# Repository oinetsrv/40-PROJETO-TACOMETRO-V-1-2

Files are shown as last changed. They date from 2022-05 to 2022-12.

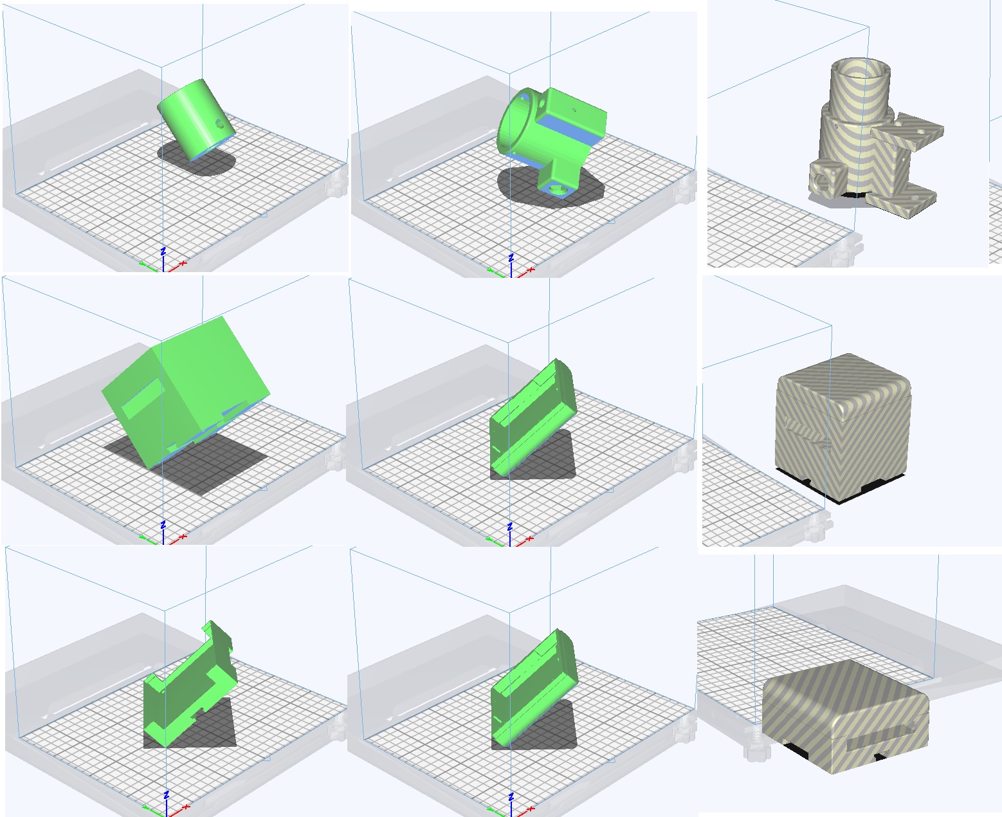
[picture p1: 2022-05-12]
DIAGRAMAS E IMAGENS/CASE-SENSOR.jpg

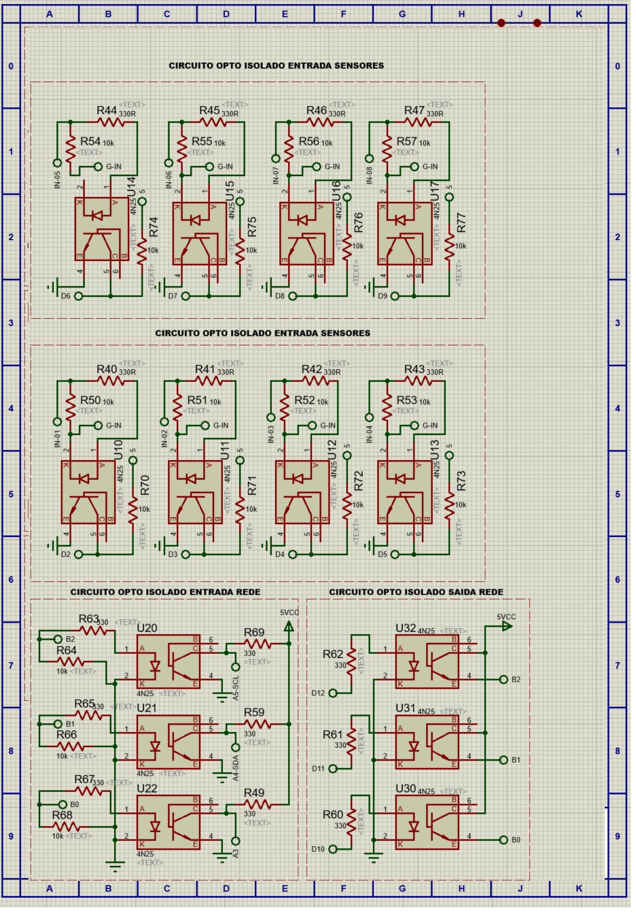
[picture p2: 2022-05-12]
DIAGRAMAS E IMAGENS/DIAGRAMA-PCB-I-O-P2.jpg

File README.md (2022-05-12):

# 40-PROJETO-TACOMETRO-V-1-2.
## MEDIDOR DE VELOCIDADE DE ROTAÇÃO USANDO MÉTODO DE INTERRUPÇÃO.
## COMUNICAÇÃO COM PROTOCOLO RS485.
## CAPACIDADE DE EXPANSÃO DAS ENTRADAS DIGITAIS EM MODULOS DE 8 ENTRADAS.
## REDE DE COMUNICAÇÃO MÁXIMA DE 4 MÓDULOS COM 8 ENTRADAS TOTAL DE SENSORES NA REDE DE 32 SENSORES.
## MODELAGEM 3D DAS CASES ADAPTADAS AO PADRÃO TRILHO DIN
## MODELAGEM 3D DA CASE DO SENSOR DE ROTAÇÃO ADAPTADA PARA FIXAÇÃO ROBUSTA NO CAMPO.
## MODELAGEM DAS PCBS DE I/O E REDE COM DIAGRAMA ELÉTRICO DETALHADO.

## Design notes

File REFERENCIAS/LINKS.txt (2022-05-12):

https://www.arduino.cc/reference/pt/language/functions/external-interrupts/attachinterrupt/

http://gammon.com.au/interrupts

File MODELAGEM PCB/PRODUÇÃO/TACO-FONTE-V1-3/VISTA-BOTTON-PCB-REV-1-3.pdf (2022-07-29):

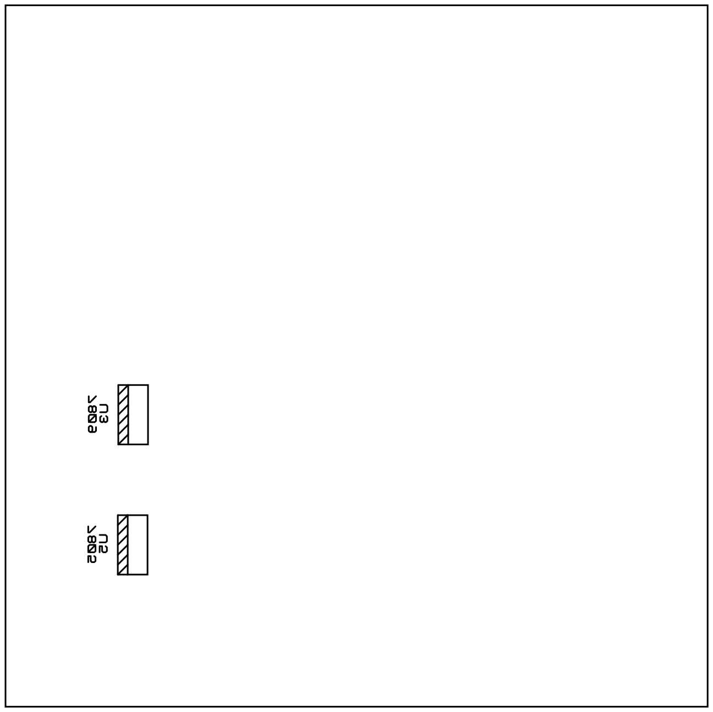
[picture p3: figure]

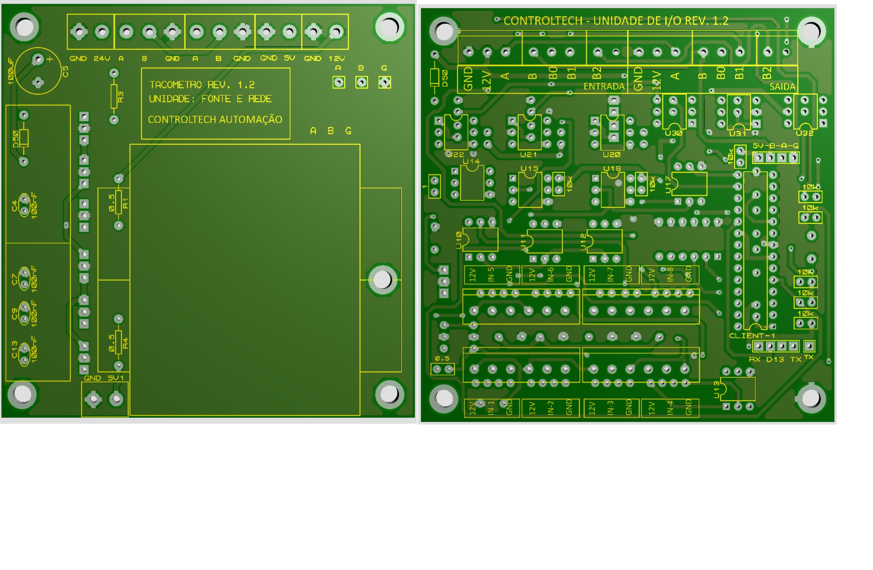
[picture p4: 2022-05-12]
DIAGRAMAS E IMAGENS/DIAGRAMA-PCB-I-O.jpg

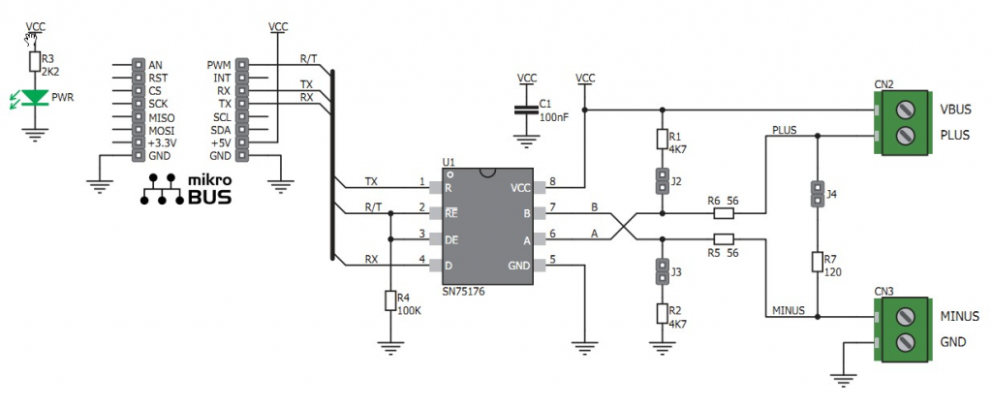
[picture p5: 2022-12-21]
REFERENCIAS/rede 485.png

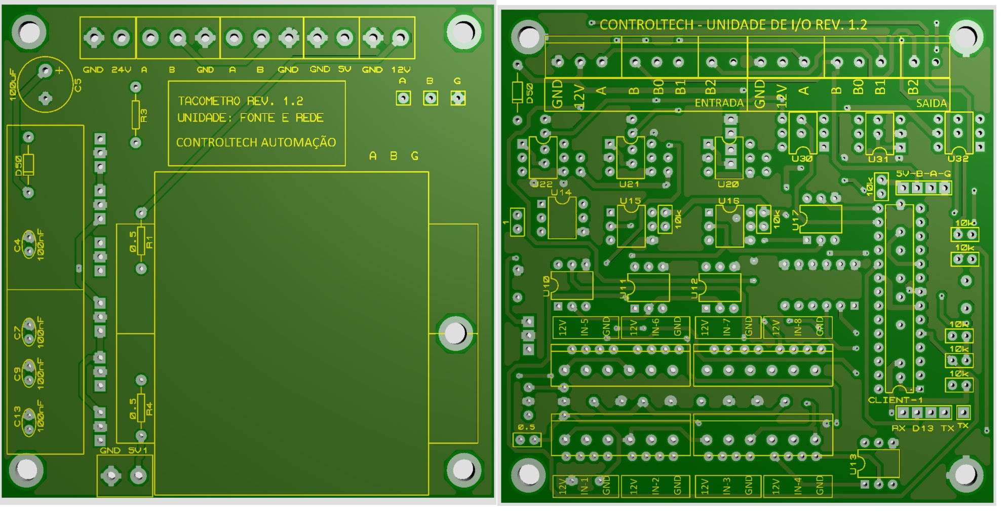
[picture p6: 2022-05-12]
DIAGRAMAS E IMAGENS/LAYOUT_PCBS.jpg

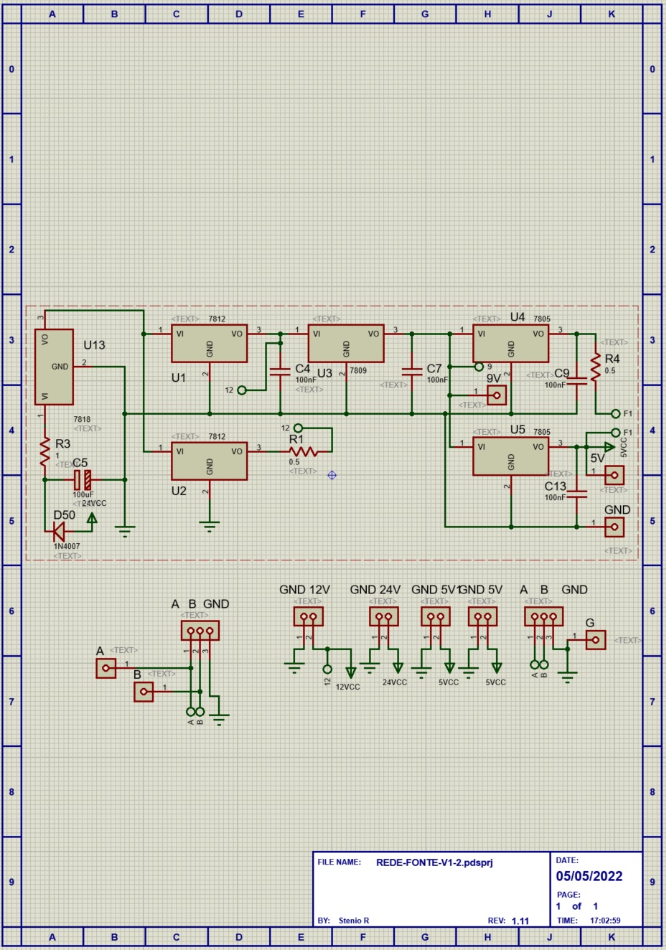
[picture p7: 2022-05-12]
DIAGRAMAS E IMAGENS/DIAGRAMA-PCB-FONTE-REDE.jpg

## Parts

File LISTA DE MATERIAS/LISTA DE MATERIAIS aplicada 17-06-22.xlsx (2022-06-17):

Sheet: MATERIAIS
 |  | FORNECIMENTO DE TACOMETRO ARMAZÉM DE GRÃOS |  |  |  |  |  | CLIENTE: TACOMETRO | PROPOSTA: 20221001 | REVISÃO: 01 | DATA DA PROPOSTA: 14/03/2022 | SOLICITANTE: HUGO
 |  |  |  |  |  |  |  |  |  |  |  |  |  | 50%
 | EQUIPAMENTOS
ITEM | DESCRIÇÃO | LOCAL | APLICAÇÃO | COD | UNID. | QUANT. | IPI | R$ Unit. S/ IPI | R$ Unit. C/ IPI | R$ Total Compra | MARG. % | R$ Unit. | R$ Total
1 | 08 SENSORES DE ROTAÇÃO
2 | EIXO PERFURADO TORNO |  | SENSOR |  | PÇ | 13 | 15% | R$82.00 | R$94.30 | R$1225.90 | 50% | R$141.45 | R$1838.85
3 | Fixador Magnético 36mm Furo Escareado |  | SENSOR |  | PÇ | 13 | 15% | R$92.50 | R$106.38 | R$1382.88 | 50% | R$159.56 | R$2074.31
1 | Fixador Magnético 20 Mm |  | SENSOR |  | PÇ | 13 | 15% | R$42.50 | R$48.88 | R$635.38 | 50% | R$73.31 | R$953.06
2 | SENSOR 100RPM-PNP |  | SENSOR |  | PÇ | 13 | 15% | R$112.00 | R$128.80 | R$1674.40 | 50% | R$193.20 | R$2511.60
4 | PRENSA CABO 1/8 |  | SENSOR |  | PÇ | 13 | 15% | R$3.50 | R$4.03 | R$52.33 | 50% | R$6.04 | R$78.49
6 | CASE IMPRESSÃO 3D MATERIAL COPO, BASE ROLAMENTO E PINO GUIA |  | SENSOR |  | PÇ | 13 | 15% | R$90.00 | R$103.50 | R$1345.50 | 50% | R$155.25 | R$2018.25
7 | IMPOSTO CASE 3D COPO, BASE ROLAMENTO E PINO GUIA |  | SENSOR |  | PÇ | 13 | 15% | R$60.00 | R$69.00 | R$897.00 | 50% | R$103.50 | R$1345.50
8 | PARAFUSO M4 IMA |  | SENSOR |  | PÇ | 13 | 15% | R$1.00 | R$1.15 | R$14.95 | 50% | R$1.73 | R$22.43
8 | PARAFUSO M8 BASE |  | SENSOR |  | PÇ | 26 | 15% | R$1.00 | R$1.15 | R$29.90 | 50% | R$1.73 | R$44.85
19 |  |  |  |  |  |  | 15% |  | R$0.00 | R$0.00 | 50% | R$0.00 | R$0.00
 | TOTAL MATERIAIS |  |  |  |  |  |  | R$483.50 |  | R$7258.23 |  |  | R$10887.34
 | PCB I/O
20 | CRISTAL 16MHZ |  | PCB I/O |  | PÇ | 1 | 15% | R$1.50 | R$1.73 | R$1.73 | 50% | R$2.59 | R$2.59
21 | ATMEGA328P-PU |  | PCB I/O |  | PÇ | 1 | 15% | R$35.00 | R$40.25 | R$40.25 | 50% | R$60.38 | R$60.38
22 | SOQUETE ESTAMPADO 28 PINOS ESTREITO |  | PCB I/O |  | PÇ | 8 | 15% | R$1.00 | R$1.15 | R$9.20 | 50% | R$1.73 | R$13.80
23 | CAPACITOR CERÂMICO 22PF 50V |  | PCB I/O |  | PÇ | 2 | 15% | R$0.50 | R$0.57 | R$1.15 | 50% | R$0.86 | R$1.73
24 | CAPACITOR CERÂMICO 100NF 50V |  | PCB I/O |  | PÇ | 7 | 15% | R$0.50 | R$0.57 | R$4.03 | 50% | R$0.86 | R$6.04
25 | CAPACITOR ELETROTR 100UF 50V |  | PCB I/O |  | PÇ | 0 | 15% | R$2.00 | R$2.30 | R$0.00 | 50% | R$3.45 | R$0.00
28 | METALFILME 1/4W 1% - 1K |  | PCB I/O |  | PÇ | 1 | 15% | R$0.50 | R$0.57 | R$0.57 | 50% | R$0.86 | R$0.86
29 | METALFILME 1/4W 1% - 1OHM |  | PCB I/O |  | PÇ | 1 | 15% | R$0.50 | R$0.57 | R$0.57 | 50% | R$0.86 | R$0.86
30 | METALFILME 1/4W 1% - 0.5OHM |  | PCB I/O |  | PÇ | 1 | 15% | R$0.50 | R$0.57 | R$0.57 | 50% | R$0.86 | R$0.86
31 | METALFILME 1/4W 1% - 330OHM |  | PCB I/O |  | PÇ | 20 | 15% | R$0.50 | R$0.57 | R$11.50 | 50% | R$0.86 | R$17.25
 | METALFILME 1/4W 1% - 10K |  | PCB I/O |  | PÇ | 20 | 15% | R$0.50 | R$0.57 | R$11.50 | 50% | R$0.86 | R$17.25
32 | CI 4N25 |  | PCB I/O |  | PÇ | 14 | 15% | R$3.00 | R$3.45 | R$48.30 | 50% | R$5.17 | R$72.45
 | CI 7805 |  | PCB I/O |  | PÇ | 2 | 15% | R$5.50 | R$6.33 | R$12.65 | 50% | R$9.49 | R$18.98
37 | CI 7809 |  | PCB I/O |  | PÇ | 1 | 15% | R$3.50 | R$4.03 | R$4.03 | 50% | R$6.04 | R$6.04
34 | MÓDULO ADAPTADOR TTL/RS485 |  | PCB I/O |  | PÇ | 1 | 15% | R$13.00 | R$14.95 | R$14.95 | 50% | R$22.43 | R$22.43
39 | DIODO 1N4007 |  | PCB I/O |  | PÇ | 1 | 15% | R$1.50 | R$1.73 | R$1.73 | 50% | R$2.59 | R$2.59
35 | BARRA DE PINO 1X20 MCI FÊMEA |  | PCB I/O |  | PÇ | 1 | 15% | R$9.00 | R$10.35 | R$10.35 | 50% | R$15.53 | R$15.53
 | TERMINAL DUPLO 2X6 VIAS de 3.81mm |  | PCB I/O |  | PÇ | 2 | 15% | R$16.00 | R$18.40 | R$36.80 | 50% | R$27.60 | R$55.20
 | BORNE RECEPTOR
40 | BR7MN2 - BORNE RECEPTOR 90º PASSO 3,81MM METALTEX 3VIAS |  | PCB I/O |  | PÇ | 4 | 15% | R$4.00 | R$4.60 | R$18.40 | 50% | R$6.90 | R$27.60
41 | BORNE PLUG METALTEX BR7F2 PASSO 3,81 MM 3 VIAS |  | PCB I/O |  | PÇ | 4 | 15% | R$4.50 | R$5.17 | R$20.70 | 50% | R$7.76 | R$31.05
42 | BR7MN2 - BORNE RECEPTOR 90º PASSO 3,81MM METALTEX 2VIAS |  | PCB I/O |  | PÇ | 2 | 15% | R$4.00 | R$4.60 | R$9.20 | 50% | R$6.90 | R$13.80
43 | BORNE PLUG METALTEX BR7F2 PASSO 3,81 MM 2VIAS |  | PCB I/O |  | PÇ | 2 | 15% | R$4.50 | R$5.17 | R$10.35 | 50% | R$7.76 | R$15.53
44 | PCB I/0 IMPORTADA PRINCIPAL |  | PCB I/O |  | PÇ | 1 | 15% | R$39.00 | R$44.85 | R$44.85 | 50% | R$67.28 | R$67.28
7 | IMPOSTO PCB |  | PCB I/O |  | PÇ | 1 | 15% | R$20.00 | R$23.00 | R$23.00 | 50% | R$34.50 | R$34.50
47 | DIP SWITCH 6 VIAS 180º |  | PCB I/O |  | PÇ | 1 | 15% | R$12.00 | R$13.80 | R$13.80 | 50% | R$20.70 | R$20.70
 | PARAFUSO M8 50MM |  | PCB I/O |  | PÇ | 4 | 15% | R$1.00 | R$1.15 | R$4.60 | 50% | R$1.73 | R$6.90
 | PORCA M8 |  | PCB I/O |  | PÇ | 16 | 15% | R$1.00 | R$1.15 | R$18.40 | 50% | R$1.73 | R$27.60
49 | CASE IMPRESSÃO 3D MATERIAL CASE E TAMPA |  | PCB I/O |  | PÇ | 1 | 15% | R$65.00 | R$74.75 | R$74.75 | 50% | R$112.12 | R$112.12
7 | IMPOSTO IMPRESSÃO CASE E TAMPA |  | PCB I/O |  | PÇ | 13 | 15% | R$35.00 | R$40.25 | R$523.25 | 50% | R$60.38 | R$784.88
 | QUANTIDADE DE PLACAS PARA A QUANTIDADE DE SENSORES |  |  |  |  | 1 |  | R$963.00 | R$963.00 | R$963.00 | 50% | R$1444.50 | R$1444.50
59 |  |  |  |  |  |  | 15% |  | R$0.00 | R$0.00 | 50% | R$0.00 | R$0.00
 | TOTAL MATERIAIS |  |  |  |  |  |  |  |  | R$1934.17 |  |  | R$2901.26
 | PCB REDE
24 | CAPACITOR CERÂMICO 100NF 50V |  | PCB REDE |  | PÇ | 3 | 15% | R$0.50 | R$0.57 | R$1.73 | 50% | R$0.86 | R$2.59
25 | CAPACITOR ELETROTR 100UF 50V |  | PCB REDE |  | PÇ | 0 | 15% | R$2.00 | R$2.30 | R$0.00 | 50% | R$3.45 | R$0.00
29 | METALFILME 1/4W 1% - 1OHM |  | PCB REDE |  | PÇ | 1 | 15% | R$0.50 | R$0.57 | R$0.57 | 50% | R$0.86 | R$0.86
30 | METALFILME 1/4W 1% - 0.5OHM |  | PCB REDE |  | PÇ | 0 | 15% | R$0.50 | R$0.57 | R$0.00 | 50% | R$0.86 | R$0.00
 | CI 7805 |  | PCB REDE |  | PÇ | 1 | 15% | R$5.50 | R$6.33 | R$6.33 | 50% | R$9.49 | R$9.49
37 | CI 7809 |  | PCB REDE |  | PÇ | 1 | 15% | R$6.30 | R$7.25 | R$7.25 | 50% | R$10.87 | R$10.87
 | CI 7812 |  | PCB REDE |  | PÇ | 0 | 15% | R$6.50 | R$7.47 | R$0.00 | 50% | R$11.21 | R$0.00
37 | CI 7818 |  | PCB REDE |  | PÇ | 0 | 15% | R$11.00 | R$12.65 | R$0.00 | 50% | R$18.98 | R$0.00
39 | DIODO 1N4007 |  | PCB REDE |  | PÇ | 1 | 15% | R$1.50 | R$1.73 | R$1.73 | 50% | R$2.59 | R$2.59
40 | BR7MN2 - BORNE RECEPTOR 90º PASSO 3,81MM METALTEX 3VIAS |  | PCB REDE |  | PÇ | 2 | 15% | R$4.00 | R$4.60 | R$9.20 | 50% | R$6.90 | R$13.80
41 | BORNE PLUG METALTEX BR7F2 PASSO 3,81 MM 3 VIAS |  | PCB REDE |  | PÇ | 2 | 15% | R$4.50 | R$5.17 | R$10.35 | 50% | R$7.76 | R$15.53
42 | BR7MN2 - BORNE RECEPTOR 90º PASSO 3,81MM METALTEX 2VIAS |  | PCB REDE |  | PÇ | 3 | 15% | R$4.00 | R$4.60 | R$13.80 | 50% | R$6.90 | R$20.70
43 | BORNE PLUG METALTEX BR7F2 PASSO 3,81 MM 2VIAS |  | PCB REDE |  | PÇ | 3 | 15% | R$4.50 | R$5.17 | R$15.53 | 50% | R$7.76 | R$23.29
64 | PCB I/0 IMPORTADA PRINCIPAL |  | PCB REDE |  | PÇ | 1 | 15% | R$35.00 | R$40.25 | R$40.25 | 50% | R$60.38 | R$60.38
7 | IMPOSTO PCB |  | PCB REDE |  | PÇ | 1 | 15% | R$20.00 | R$23.00 | R$23.00 | 50% | R$34.50 | R$34.50
 | PARAFUSO M8 50MM |  | PCB REDE |  | PÇ | 4 | 15% | R$1.00 | R$1.15 | R$4.60 | 50% | R$1.73 | R$6.90
 | PORCA M8 |  | PCB REDE |  | PÇ | 16 | 15% | R$1.00 | R$1.15 | R$18.40 | 50% | R$1.73 | R$27.60
49 | CASE IMPRESSÃO 3D MATERIAL CASE E TAMPA |  | PCB REDE |  | PÇ | 1 | 15% | R$65.00 | R$74.75 | R$74.75 | 50% | R$112.12 | R$112.12
7 | IMPOSTO IMPRESSÃO CASE E TAMPA |  | PCB REDE |  | PÇ | 13 | 15% | R$35.00 | R$40.25 | R$523.25 | 50% | R$60.38 | R$784.88
69 | CONVERSOR USR-TCP232-410S SUPORT DNS DHCP RS232 RS485 SERIAL |  | PCB REDE |  | PÇ | 1 | 15% | R$425.00 | R$488.75 | R$488.75 | 50% | R$733.12 | R$733.12
 | QUANTIDADE DE PLACAS PARA A QUANTIDADE DE SENSORES |  |  |  |  | 1 |  | R$963.00 | R$963.00 | R$963.00 | 50% | R$1444.50 | R$1444.50
78 |  |  |  |  |  |  | 15% |  | R$0.00 | R$0.00 | 50% | R$0.00 | R$0.00
 | TOTAL MATERIAIS |  |  |  |  |  |  |  |  | R$2202.47 |  |  | R$3303.70
84
85
86
87
88
100
 | TOTAL MATERIAIS CONTEMPLA 12 SENSORES, 2 PLACA I/O E 1 PLACA DE REDE |  |  |  |  |  |  |  |  | R$0.00 |  |  | R$17092.31
49 | TOTAL MÃO DE OBRA |  |  |  |  |  |  |  |  |  |  |  | #NAME?
 | TOTAL PROPOSTA |  |  |  |  |  |  |  |  |  |  |  | #NAME?
 |  |  |  |  |  |  |  |  |  |  |  |  | R$5127.69
 |  |  |  |  |  |  |  |  |  |  |  |  | #NAME?

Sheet: MO
MÃO DE OBRA
ITEM | DESCRIÇÃO | DIAS | H. DIA | HORAS | OFICIAL | AJUD. | T. FUNC. | R$ OFICIAL | R$ AJUD. | R$ M-O | MAR. % | R$ M-O T. | HOSP. | T. HOSP | ALIM. | T. ALIM. | KM | KM TOTAL | R$ KM | R$ T. KM | ADICIONAL | TOTAL | TOTAL+ADIC.
1 | INFRAESTRUTURA, FIXAÇÃO DO PAINEL E PASSAGEM DE CABOS | 4 | 8 | 32 | 1 | 2 | 3 | R$65.00 | R$35.00 | R$4320.00 | 30% | R$5616.00 | R$75.00 | R$900.00 | R$25.00 | R$300.00 |  | 0 | R$1.44 | R$0.00 | R$2500.00 | R$6816.00 | R$9316.00
2 | PASSAGEM DE CABOS | 2 | 8 | 16 | 1 | 2 | 3 | R$65.00 | R$35.00 | R$2160.00 | 30% | R$2808.00 | R$75.00 | R$450.00 | R$25.00 | R$150.00 |  | 0 | R$1.44 | R$0.00 |  | R$3408.00 | R$3408.00
3 |  |  | 8 | 0 | 1 | 3 | 4 | R$65.00 | R$35.00 | R$0.00 | 30% | R$0.00 |  | R$0.00 | R$25.00 | R$0.00 |  | 0 | R$1.44 | R$0.00 |  | R$0.00 | R$0.00
4 |  |  | 8 | 0 | 1 | 3 | 4 | R$65.00 | R$35.00 | R$0.00 | 30% | R$0.00 |  | R$0.00 | R$25.00 | R$0.00 |  | 0 | R$1.44 | R$0.00 |  | R$0.00 | R$0.00
5 |  |  | 8 | 0 | 1 | 3 | 4 | R$65.00 | R$35.00 | R$0.00 | 30% | R$0.00 |  | R$0.00 | R$25.00 | R$0.00 |  | 0 | R$1.44 | R$0.00 |  | R$0.00 | R$0.00
6 |  |  | 8 | 0 | 1 | 2 | 3 | R$90.00 | R$45.00 | R$0.00 | 30% | R$0.00 |  | R$0.00 | R$25.00 | R$0.00 |  | 0 | R$1.44 | R$0.00 |  | R$0.00 | R$0.00
7 |  |  | 8 | 0 | 1 | 2 | 3 | R$90.00 | R$45.00 | R$0.00 | 30% | R$0.00 |  | R$0.00 | R$25.00 | R$0.00 |  | 0 | R$1.44 | R$0.00 |  | R$0.00 | R$0.00
 |  |  |  |  |  |  |  |  |  |  |  |  |  |  |  |  |  |  |  |  |  |  | R$1017.92
 |  |  |  |  |  |  |  |  |  |  |  |  |  |  |  |  |  |  |  |  | TOTAL ELETRICA |  | R$12724.00
 |  |  |  |  |  |  |  |  |  |  |  |  |  |  | FORNECIMENTO CONTROL TECH
 |  |  |  |  |  |  |  |  |  |  |  |  |  |  | ITEM | DESCRIÇÃO |  |  |  |  |  | DESC. | R$ VALOR
 |  |  |  |  |  |  |  |  |  |  |  |  |  |  | 1 | INFRAESTRUTURA, FIXAÇÃO DO PAINEL E PASSAGEM DE CABOS |  |  |  |  |  | SERVIÇO | R$13741.92
 |  |  |  |  |  |  | AUT | R$0.00 |  | 0.00% |  | R$0.00 |  |  | 2 | PASSAGEM DE CABOS |  |  |  |  |  | SERVIÇO
 |  |  |  |  |  |  | ELE | R$12724.00 |  | 100.00% |  | R$13741.92 |  |  | 3 |  |  |  |  |  |  | SERVIÇO
 |  |  |  |  |  |  |  |  |  |  |  |  |  |  | 4 |  |  |  |  |  |  | SERVIÇO
 |  |  |  |  |  |  |  |  |  |  |  |  |  |  | 5 |  |  |  |  |  |  | SERVIÇO
 |  |  |  |  |  |  |  |  |  |  |  |  |  |  | 6 |  |  |  |  |  |  | SERVIÇO
 |  |  |  |  |  |  |  |  |  |  |  |  |  |  | 7 |  |  |  |  |  |  | SERVIÇO
 |  |  |  |  |  |  |  |  |  |  |  |  |  |  | 8 |  |  |  |  |  |  | SERVIÇO
 |  |  |  |  |  |  |  |  |  |  |  |  |  |  | 9 |  |  |  |  |  |  | SERVIÇO
 |  |  |  |  |  |  |  |  |  |  |  |  |  |  | 10 |  |  |  |  |  |  | SERVIÇO
 |  |  |  |  |  |  |  |  |  |  |  |  |  |  |  | VALOR MÃO DE OBRA |  |  |  |  |  |  | R$13741.92

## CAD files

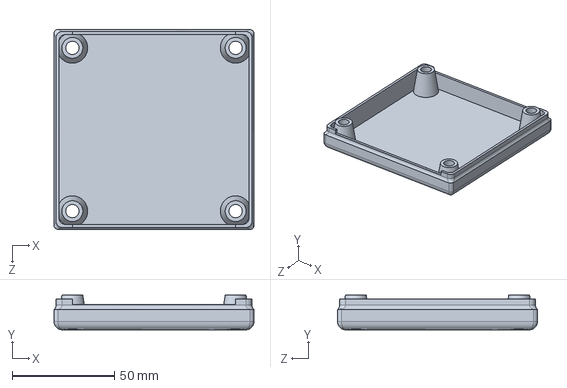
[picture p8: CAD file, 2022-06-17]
MODELAGEM 3D/PRODUÇÃO/CASE TAMPA V8.SLDPRT
98.0 x 17.0 x 98.0 mm

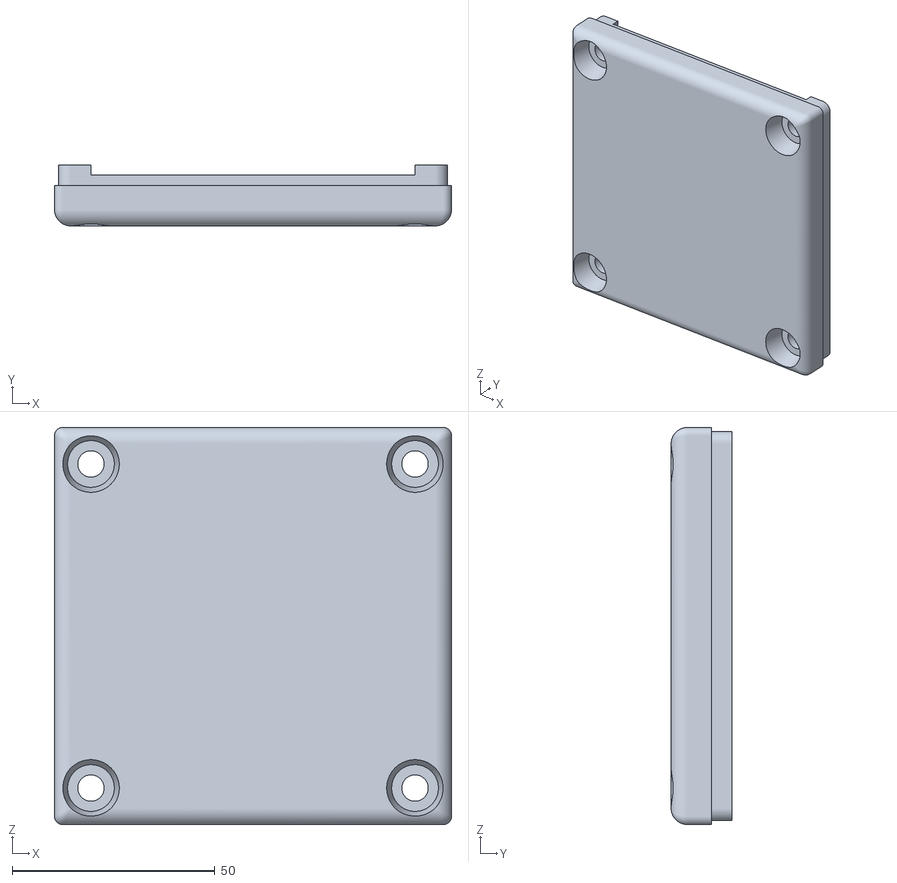
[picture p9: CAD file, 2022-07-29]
MODELAGEM 3D/PRODUÇÃO25-07/CASE IO TAMPA V9.STL
98.0 x 15.0 x 98.0

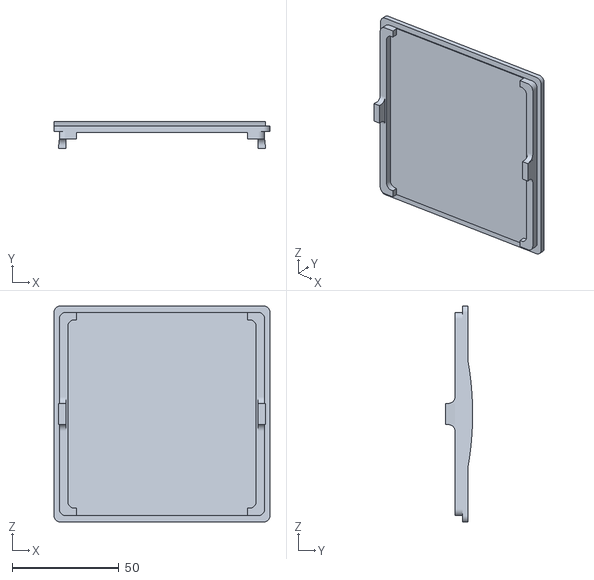
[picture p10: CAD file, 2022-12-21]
MODELAGEM 3D/CASE TAMPA V12.STL
101.0 x 12.7 x 101.0

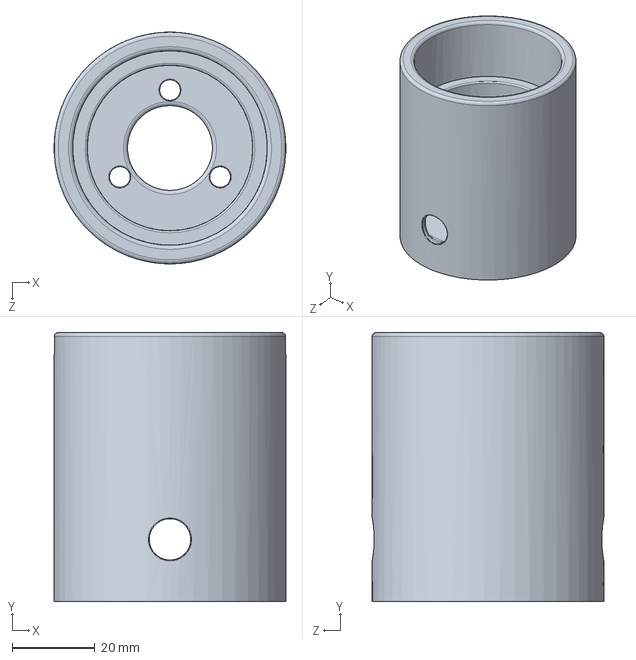
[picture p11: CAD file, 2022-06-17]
MODELAGEM 3D/PRODUÇÃO/BASE-ROLAMENTO-V2.SLDPRT
56.0 x 65.0 x 56.0 mm

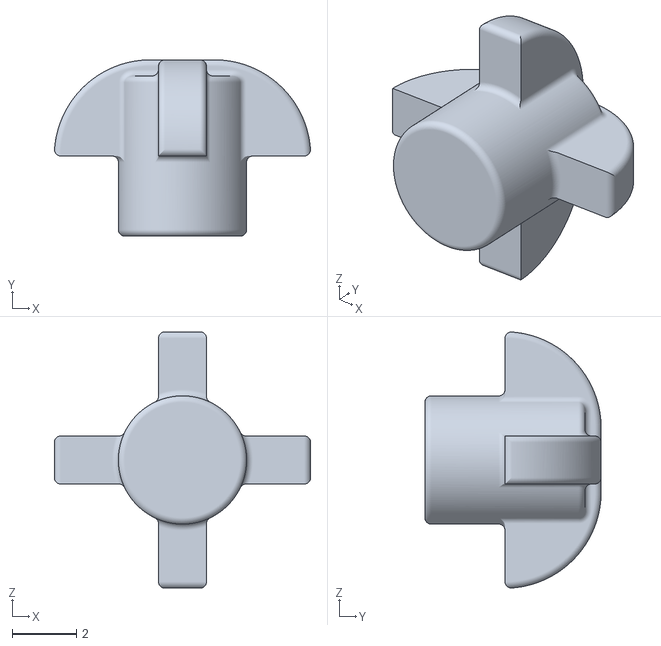
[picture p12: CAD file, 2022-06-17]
MODELAGEM 3D/PRODUÇÃO25-07/PINO-GUIA-V2.STL
7.99 x 5.50 x 7.99

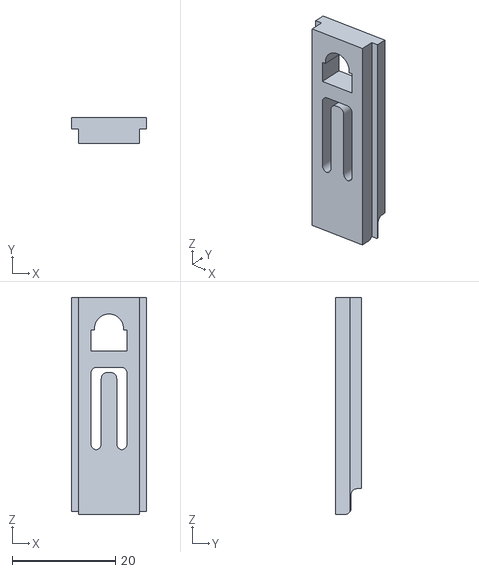
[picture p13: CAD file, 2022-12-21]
MODELAGEM 3D/PINO-TRAVA-DIN-V2.STL
14.5 x 5.00 x 42.0

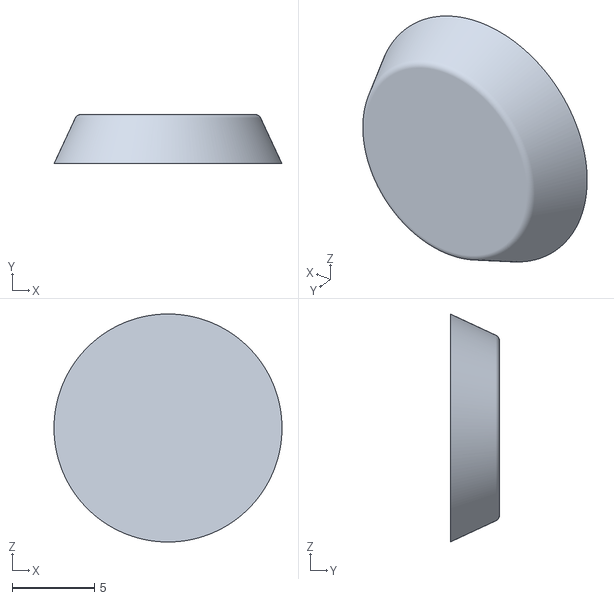
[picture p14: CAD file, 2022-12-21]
MODELAGEM 3D/CAIXA-TAMPA-PARAFUSO.STL
13.9 x 3.00 x 13.9

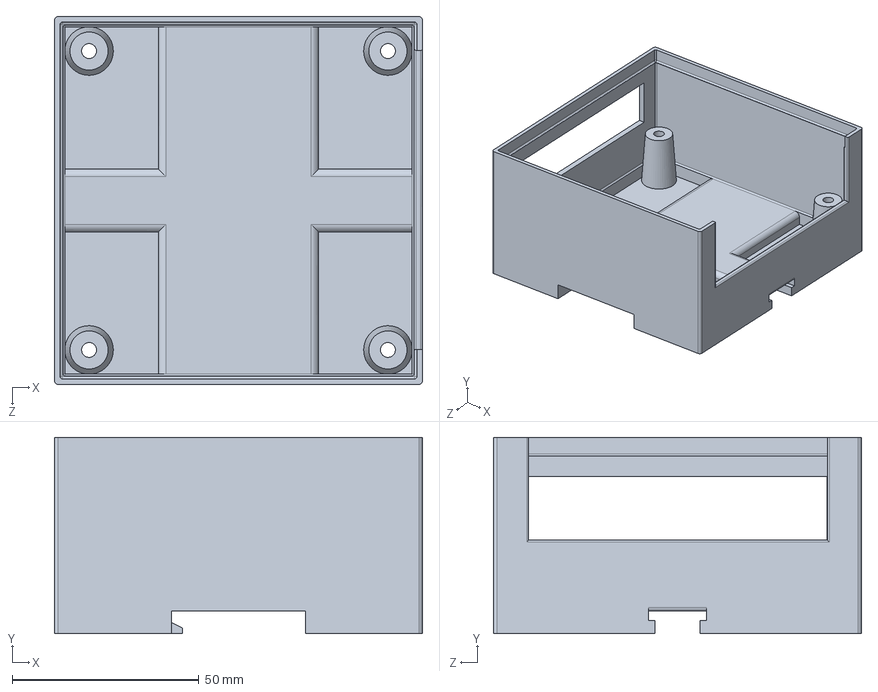
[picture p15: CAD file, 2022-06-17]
MODELAGEM 3D/PRODUÇÃO/CASE IO V7.SLDPRT
98.5 x 52.5 x 98.5 mm

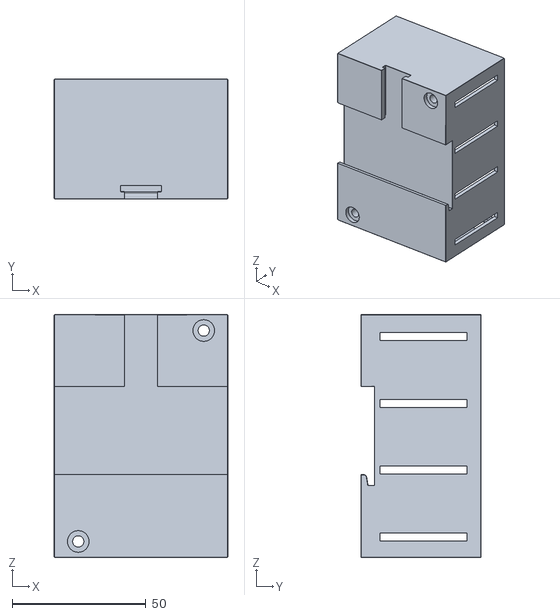
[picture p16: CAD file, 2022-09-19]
MODELAGEM 3D/CAIXA-DIN-REDE-V5.STL
65.0 x 45.0 x 91.0

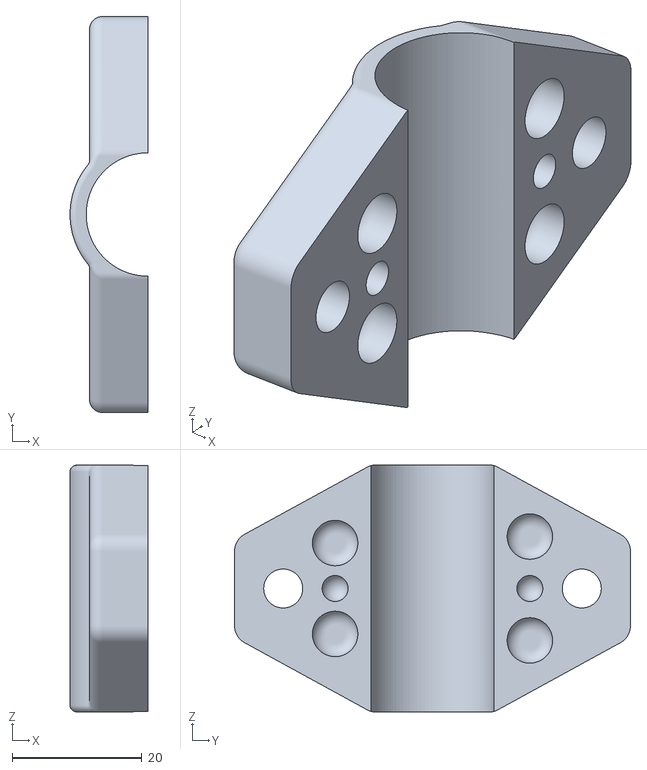
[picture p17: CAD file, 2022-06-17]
MODELAGEM 3D/PRODUÇÃO/COLAR-P1-V2.STL
12.0 x 61.0 x 38.0

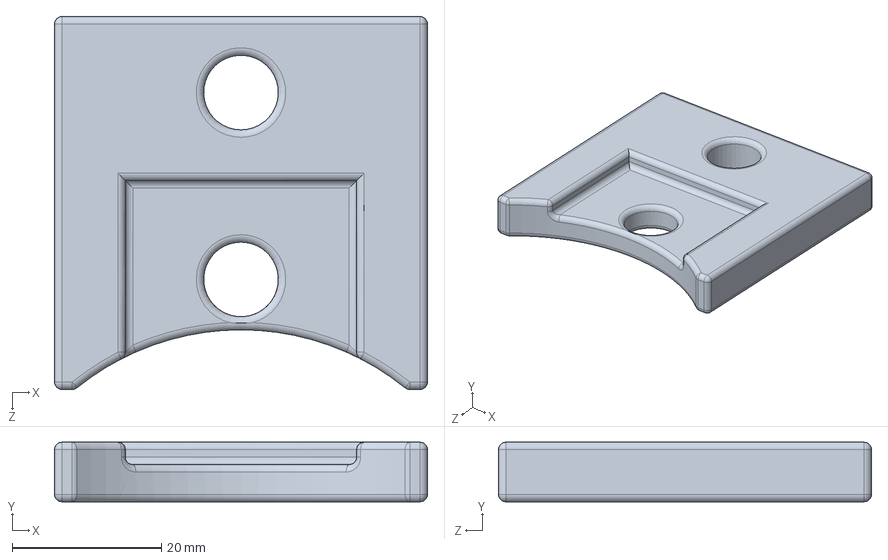
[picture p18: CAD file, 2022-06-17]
MODELAGEM 3D/PRODUÇÃO/SUPORTE-EXTENSOR-V3.SLDPRT
50.0 x 8.00 x 50.0 mm

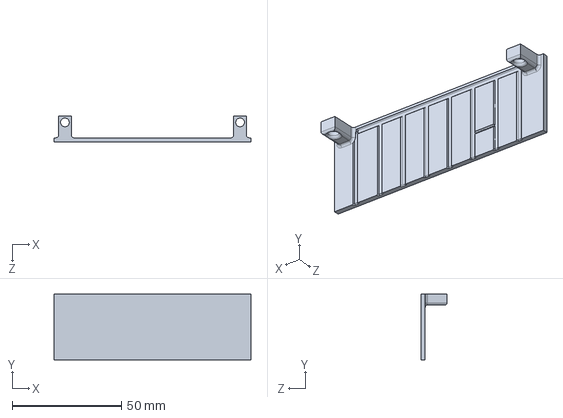
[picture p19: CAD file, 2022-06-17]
MODELAGEM 3D/CASE-ESPELHO-V1.SLDPRT
90.0 x 30.0 x 12.0 mm

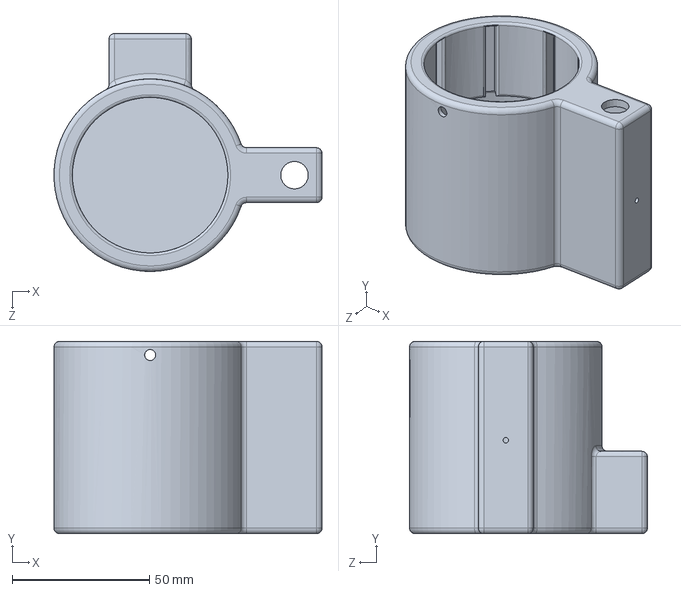
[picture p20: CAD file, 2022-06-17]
MODELAGEM 3D/PRODUÇÃO/COPO-ROLAMENTO-V10.SLDPRT
97.5 x 70.0 x 86.5 mm

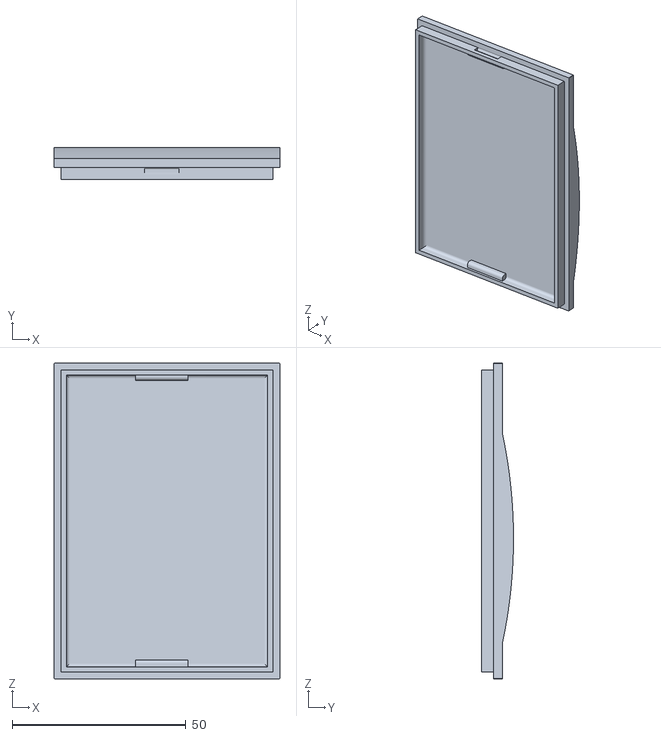
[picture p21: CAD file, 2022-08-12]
MODELAGEM 3D/versoes anteriores/CAIXA-DIN-TAMPA-REDE-V4.STL
65.0 x 9.22 x 91.0

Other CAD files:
MODELAGEM 3D/PRODUÇÃO/PINO-GUIA-V2.SLDPRT
MODELAGEM 3D/CAIXA-DIN-TAMPA-FONTE-V5.STL
MODELAGEM 3D/COLAR-P1-V2.SLDPRT
MODELAGEM 3D/CASE TAMPA V11.STL
MODELAGEM 3D/PRODUÇÃO/CASE IO V7.STL
MODELAGEM 3D/PRODUÇÃO/CASE TAMPA V8.STL
MODELAGEM 3D/PRODUÇÃO/SUPORTE-EXTENSOR-V3.STL
MODELAGEM 3D/versoes anteriores/CAIXA-DIN-FONTE-V1.STL
MODELAGEM 3D/versoes anteriores/CAIXA-DIN-FONTE-V3.STL
MODELAGEM 3D/versoes anteriores/CAIXA-DIN-FONTE-V4.STL
MODELAGEM 3D/versoes anteriores/CAIXA-DIN-REDE-V1.STL
MODELAGEM 3D/versoes anteriores/CAIXA-DIN-REDE-V3.STL
MODELAGEM 3D/versoes anteriores/CAIXA-DIN-REDE-V4.STL
MODELAGEM 3D/versoes anteriores/CAIXA-DIN-TAMPA-FONTE-V1.STL
MODELAGEM 3D/versoes anteriores/CAIXA-DIN-TAMPA-FONTE-V2.STL
MODELAGEM 3D/versoes anteriores/CAIXA-DIN-TAMPA-FONTE-V3.STL
MODELAGEM 3D/versoes anteriores/CASE-ESPELHO-V1.STL
MODELAGEM 3D/versoes anteriores/COLAR-P2-V2.SLDPRT
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

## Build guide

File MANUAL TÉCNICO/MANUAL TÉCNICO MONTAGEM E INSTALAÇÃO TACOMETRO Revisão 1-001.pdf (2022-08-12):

# MANUAL TÉCNICO

## MONTAGEM E INSTALAÇÃO

## MONITOR DE ROTAÇÃO – CTS100

# CONTROLTECH AUTOMAÇÃO INDUSTRIAL

Revisão 1.001

Rio Verde, Julho de 2022

## Sumário

## 1. Lista de figuras

## 2. Introdução

Este é um sistema composto por uma fonte de alimentação dedicada, placa conversora de

sinais mistos, placa de comunicação conversora de protocolos de comunicação e sensor de

rotação. Funciona monitorando a rotação de motores a fim de detectar rotações excessivas ou

baixas. Isso é feito por monitores de rotação no qual geram pulsos proporcionais ao giro do

motor.
Devido à sua construção mecânica, possui fácil acoplamento magnético ao eixo. É uma

solução prática para problemas com monitoramento de rotação em qualquer equipamento de

eixo rotativo. Aplicado em diversos lugares como por exemplo: transportadores de correia,

elevadores, roscas transportadoras e transportadores de arraste, entre outros...

### Características técnicas:

- Leituras velocidade de 0-100 rpm;
- Possui protocolo de comunicação aberto RS485 ou Ethernet TCP/IP;
- Grau de Proteção IP65 (a prova de poeira e protegido contra jatos de água);
- Fornece informações sobre a velocidade ou rotação do eixo;
- Principais aplicações: transportadores, elevadores, misturadores, ventiladores,

bombas, trituradores e outros;

## 3. Diagrama PCB I/O CTI008 Rer. 1.6

Diagrama de montagem dos componentes da PCB I/O revisão 1.6

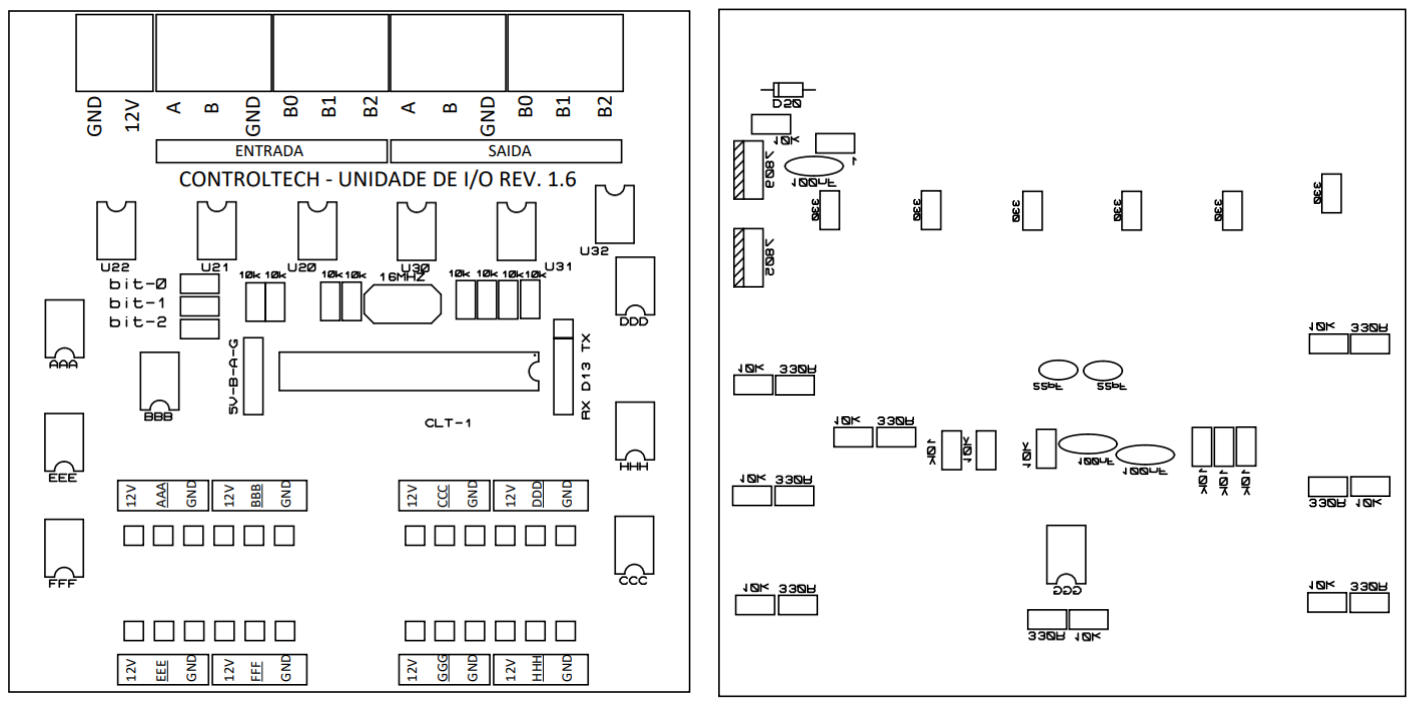
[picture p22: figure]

Figura 1: Vista superior e inferior PCB I/O Ver. 1.6

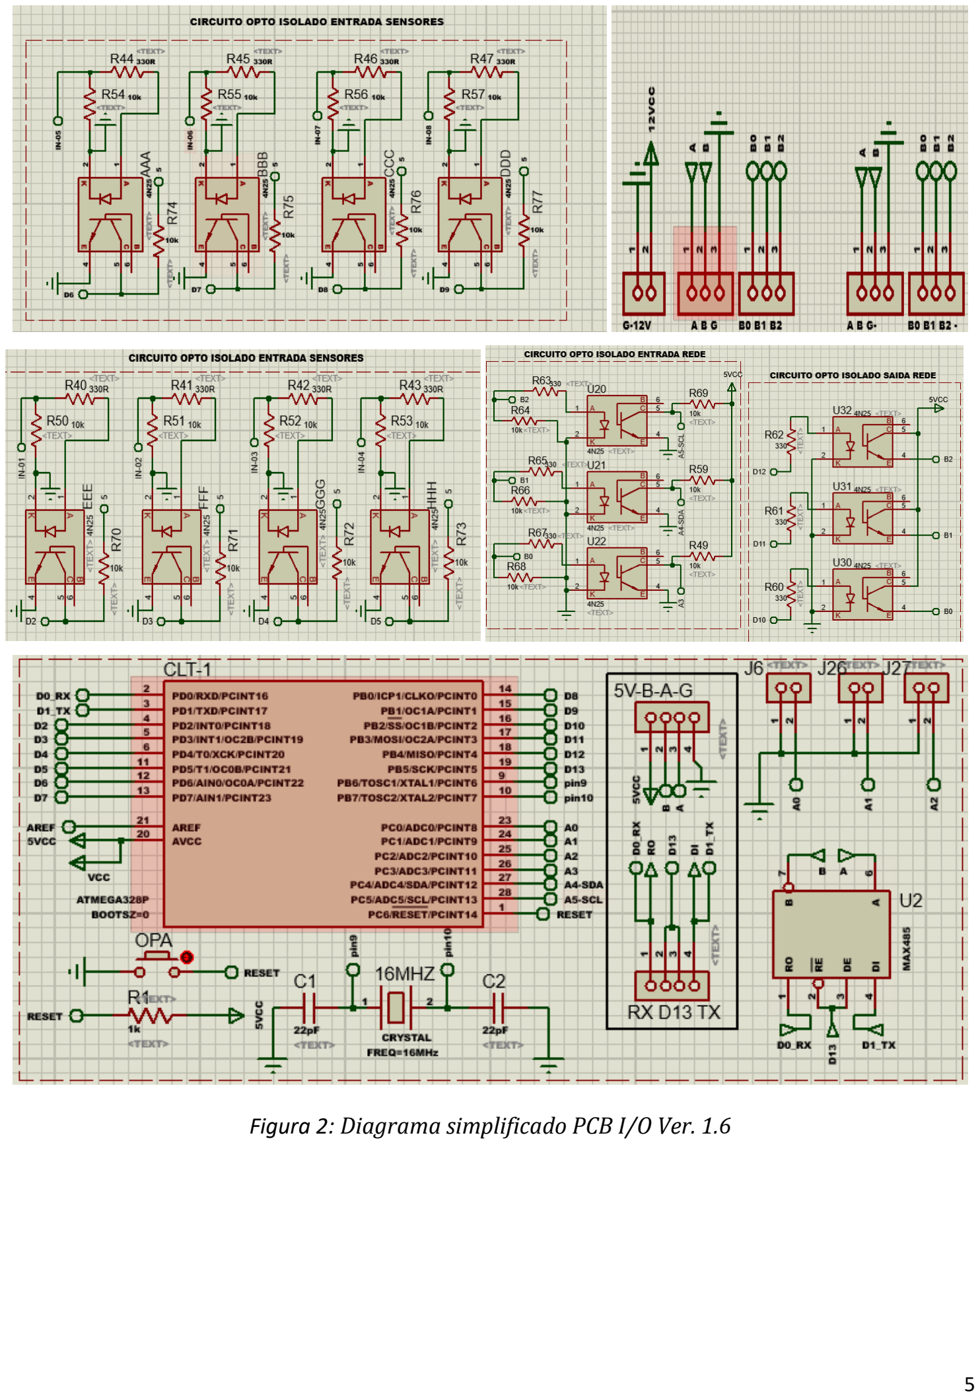
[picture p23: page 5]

Figura 2: Diagrama simplificado PCB I/O Ver. 1.6

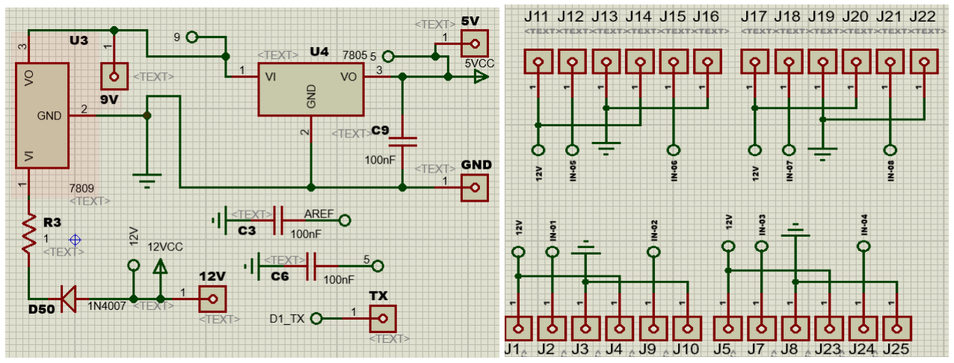
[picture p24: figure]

Figura 3: diagrama simplificado PCB I/O Ver. 1.6

### Principais componentes PCB I/O CTI008 Rer. 1.6

Os conectores identificados na PCB são os bornes modelo 2EDGVC e 2EDGVC com seus respectivos conectores.

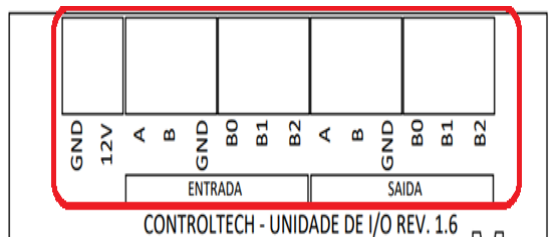
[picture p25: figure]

Figura 4: Detalhe conectores PCB I/O Ver. 1.6

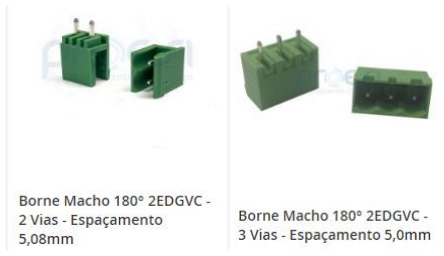
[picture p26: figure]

Figura 5: Conectores PCB

Os componentes identificados na PCB são os acopladores ópticos 4N25

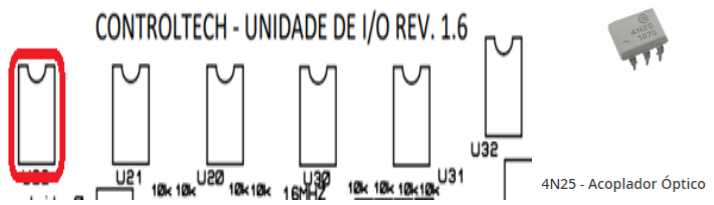
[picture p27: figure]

Figura 6: Detalhe componente 4N25 PCB I/O Ver. 1.6

Os componentes identificados na PCB com a seta verde são a matriz de jumpers, a seta azul é o cristal de 16 MHz, a seta vermelha são os resistores de 10k, a seta cinza são barras de Pinos Fêmea para conectar o modulo de comunicação RS485 e por fim a seta amarela representa o microcontrolador 328p.

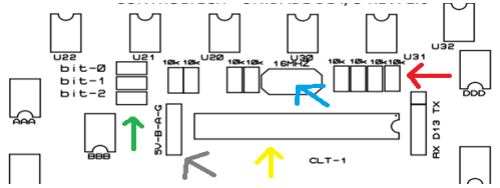
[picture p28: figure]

Figura 7: Detalhe PCB I/O Ver. 1.6

Os componentes identificados na PCB são os terminais de 3.81mm com camada dupla

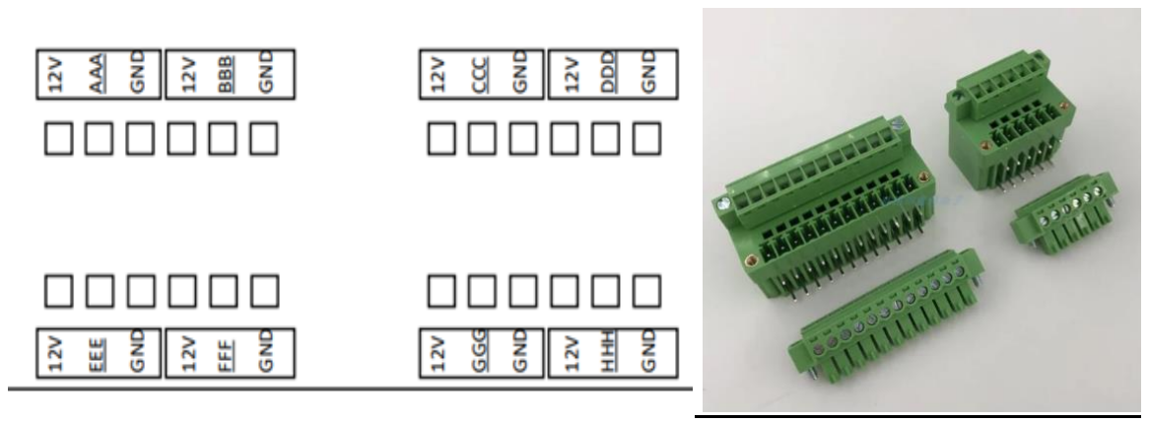
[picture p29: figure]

Figura 8: Detalhe PCB I/O Ver. 1.6 e detalhe conector entrada sensor

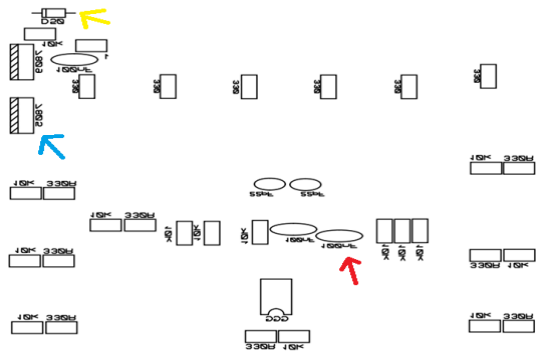
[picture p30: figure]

Figura 9: Detalhe PCB I/O Ver. 1.6

Os componentes identificados na PCB com a seta amarela é o diodo 1N4007 componente polarizado atenção ao montar. Componente identificado com a senta azul são os controladores de tensão. Componentes com a senta vermelha são capacitores.

## 4. Sensor de rotação CTS100 Rer. 1.0

Segue abaixo detalhes de montagem do sensor

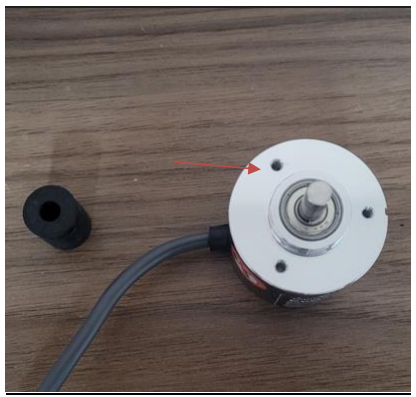
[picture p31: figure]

Figura 10: Sensor de rotação, pontos de fixação do sensor ao suporte

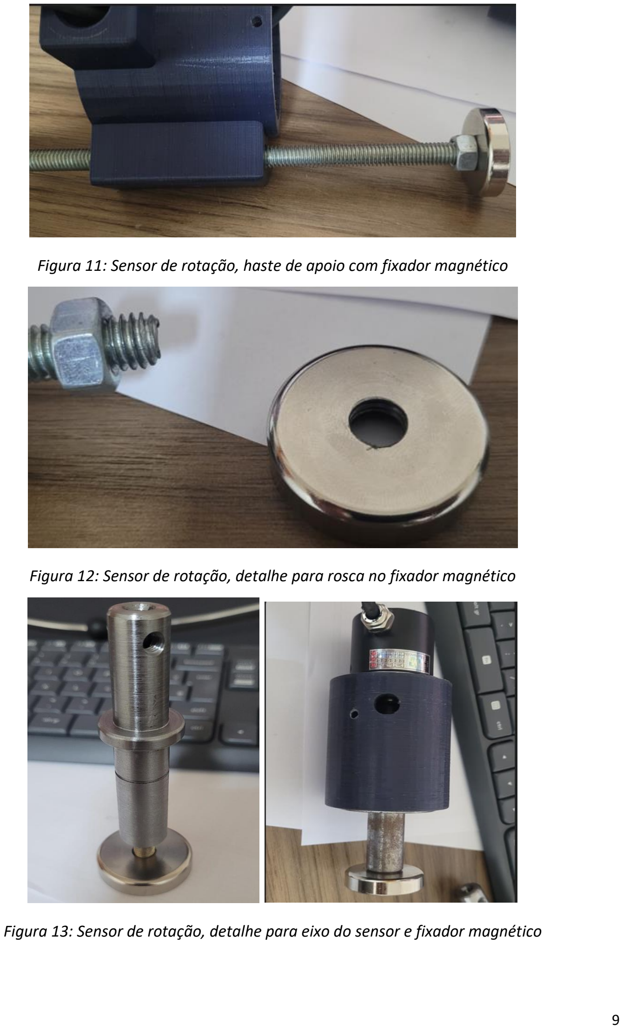
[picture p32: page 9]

Figura 11: Sensor de rotação, haste de apoio com fixador magnético

Figura 12: Sensor de rotação, detalhe para rosca no fixador magnético

Figura 13: Sensor de rotação, detalhe para eixo do sensor e fixador magnético

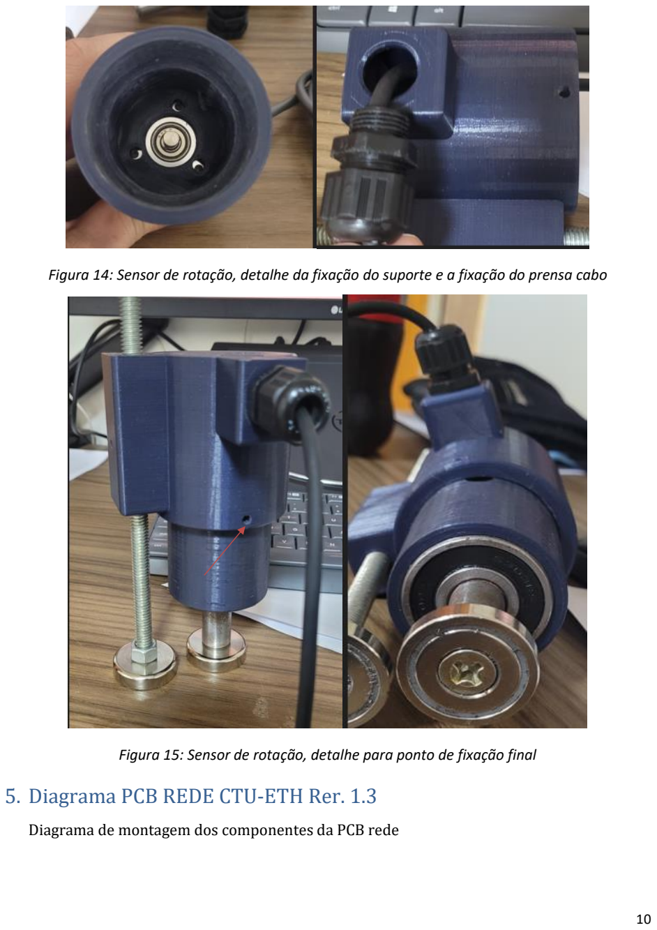
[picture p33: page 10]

Figura 14: Sensor de rotação, detalhe da fixação do suporte e a fixação do prensa cabo

Figura 15: Sensor de rotação, detalhe para ponto de fixação final

## 5. Diagrama PCB REDE CTU-ETH Rer. 1.3

Diagrama de montagem dos componentes da PCB rede

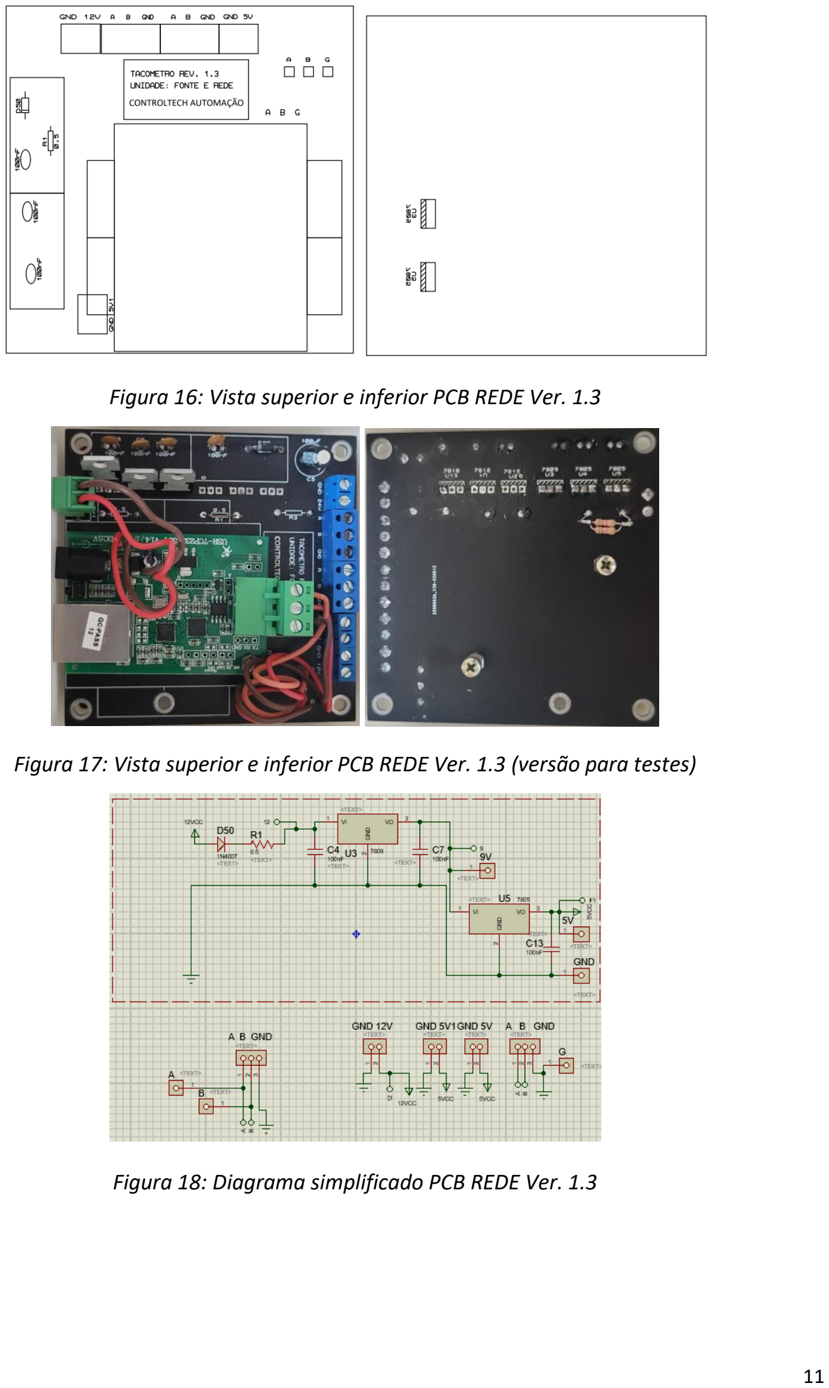
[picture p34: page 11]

Figura 16: Vista superior e inferior PCB REDE Ver. 1.3

Figura 17: Vista superior e inferior PCB REDE Ver. 1.3 (versão para testes)

Figura 18: Diagrama simplificado PCB REDE Ver. 1.3

## 6. Diagrama de instalação do conjunto placa I/O fonte de alimentação e

placa de rede.

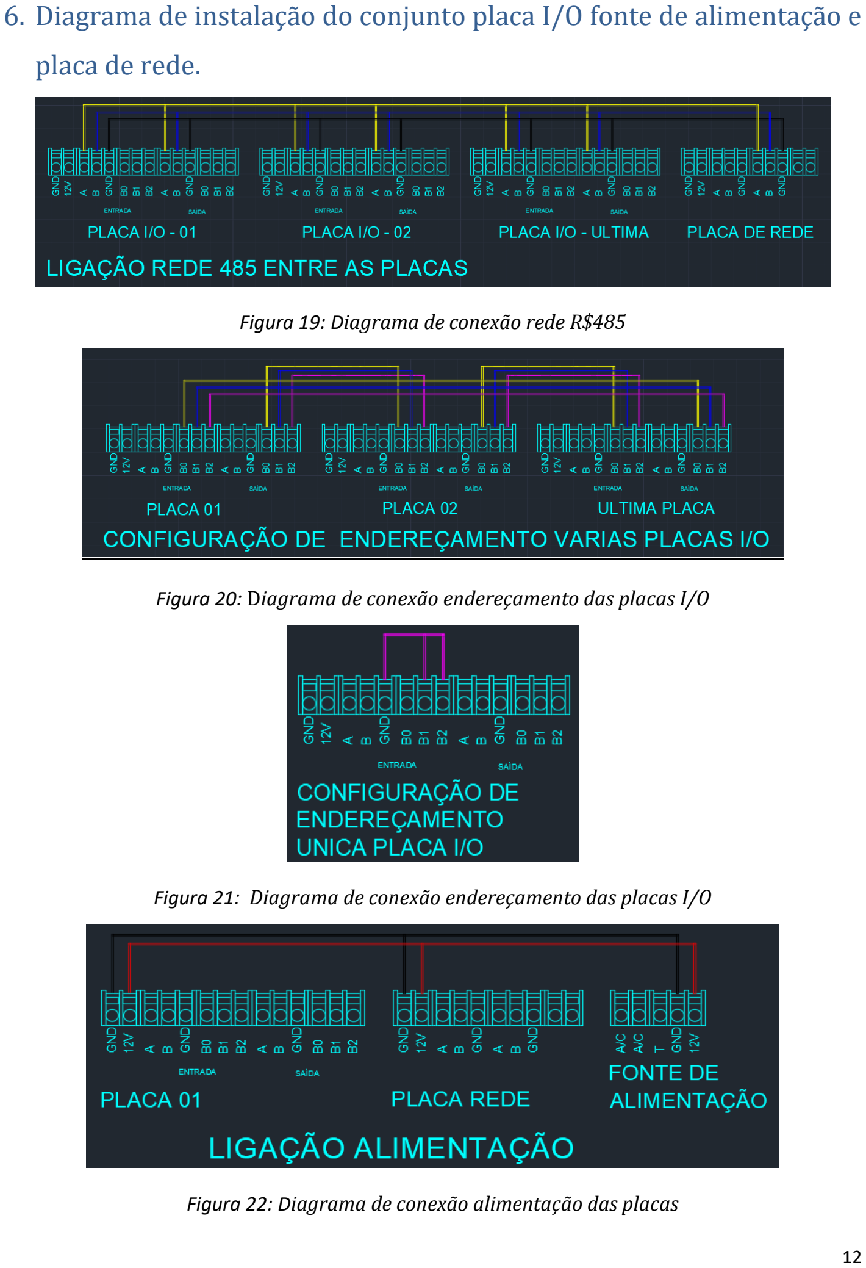
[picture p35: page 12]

Figura 19: Diagrama de conexão rede R$485

Figura 20: Diagrama de conexão endereçamento das placas I/O

Figura 21: Diagrama de conexão endereçamento das placas I/O

Figura 22: Diagrama de conexão alimentação das placas

## 7. Diagrama de instalação dos sensores na placa I/O

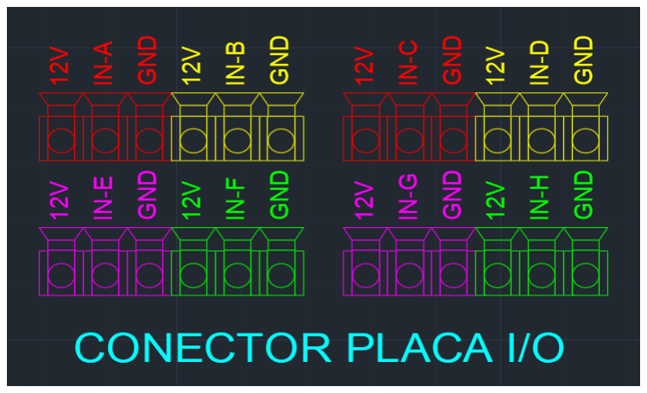
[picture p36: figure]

Figura 23: diagrama de conexão sensores de rotação

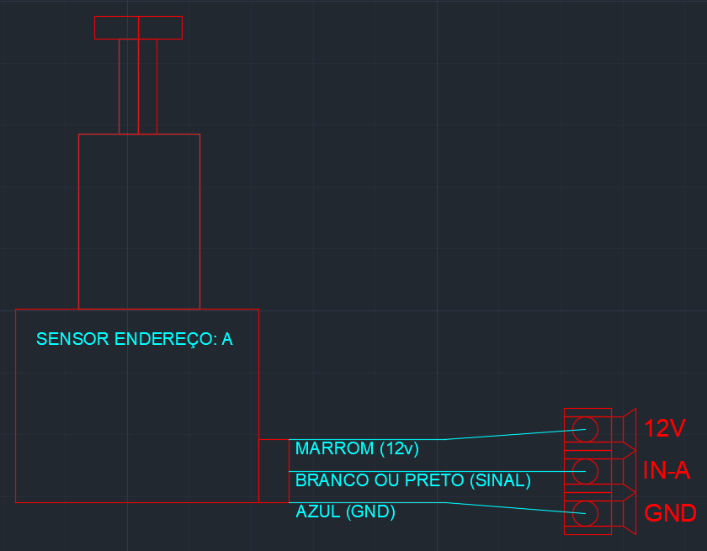
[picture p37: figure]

Figura 24: Exemplo de conexão sensores de rotação endereço A

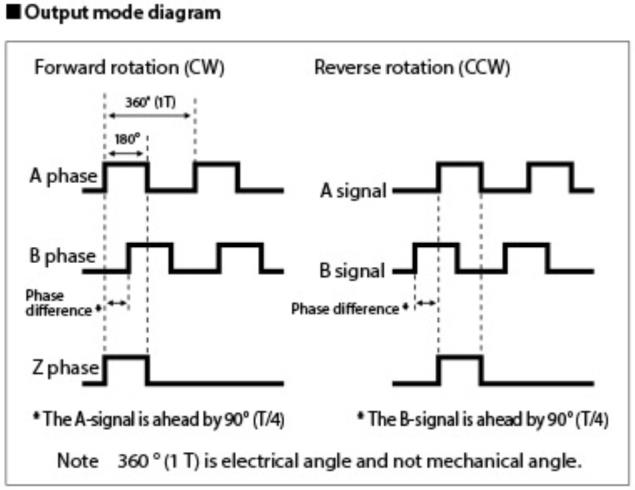
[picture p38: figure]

Figura 25: Diagrama de resposta sinais do sensor de rotação

Existe uma defasagem entre os sinais das fases A e B. Para conectar o sinal da fase “A”,

(fio preto). Para conectar o sinal da fase “B”, (fio branco). A fase Z não foi utilizada no projeto.

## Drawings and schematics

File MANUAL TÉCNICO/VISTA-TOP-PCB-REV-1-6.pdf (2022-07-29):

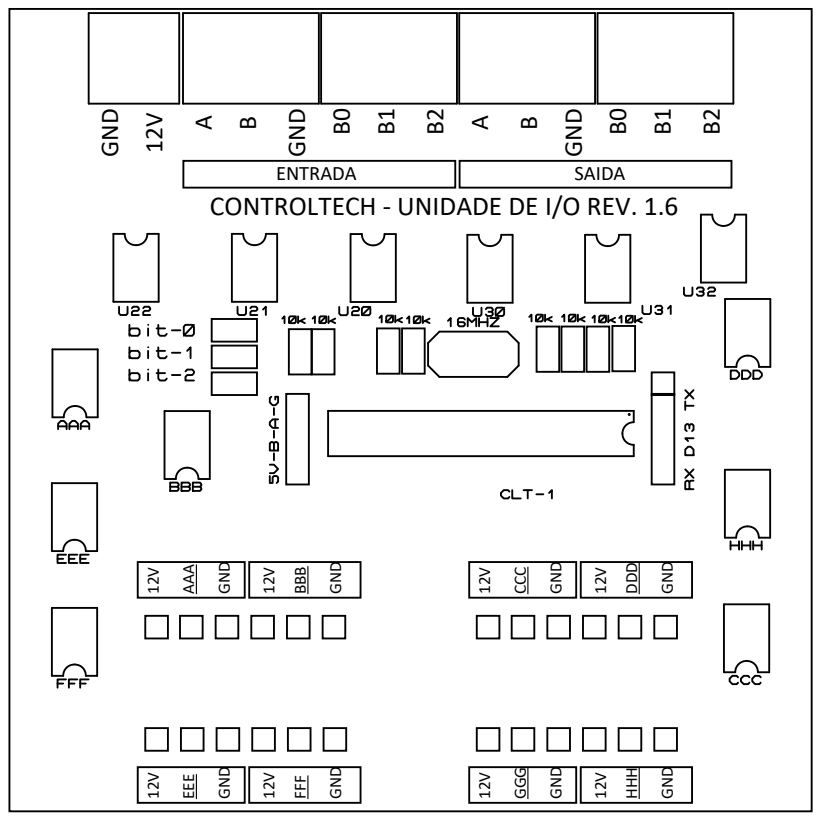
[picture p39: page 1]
CONTROLTECH - UNIDADE DE I/O REV. 1.6 GND 12V; ENTRADA; EEE; GND; 12V FFF; GGG; 12V HHH; GND ¹²V; AAA; 12V BBB; CCC; 12V DDD; GND GND; B GNDB0B1B2; SAIDA

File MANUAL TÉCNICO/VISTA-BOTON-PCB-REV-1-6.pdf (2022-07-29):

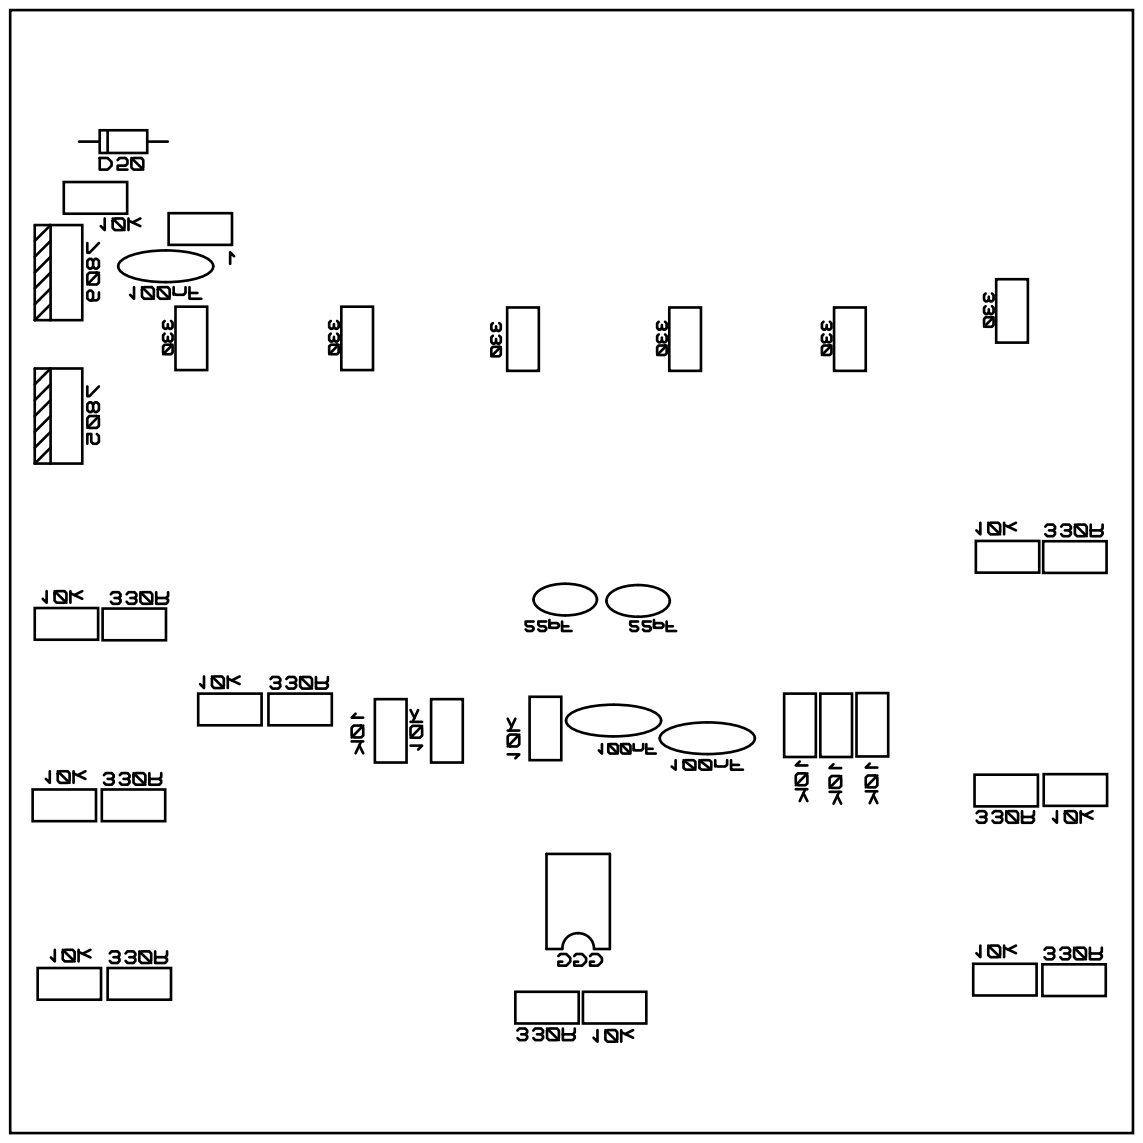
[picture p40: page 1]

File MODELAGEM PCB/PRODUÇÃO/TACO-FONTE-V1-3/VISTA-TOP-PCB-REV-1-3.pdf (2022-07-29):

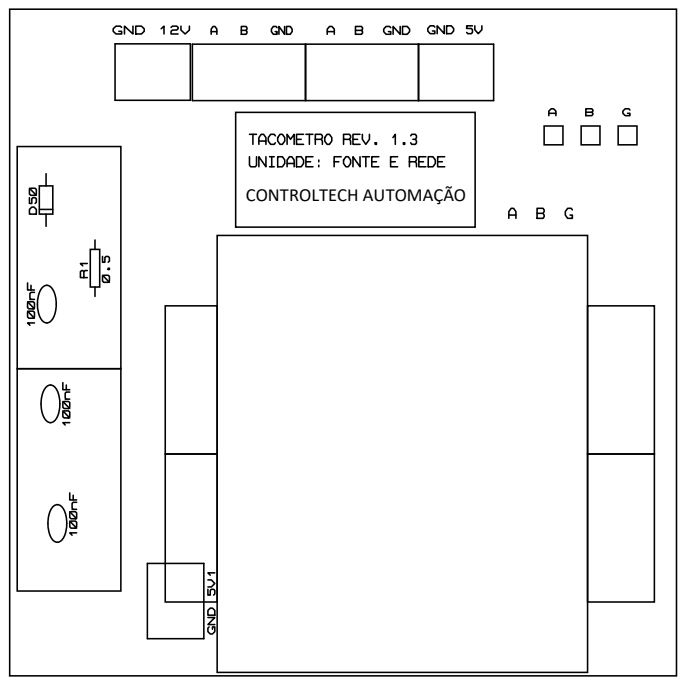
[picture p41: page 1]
CONTROLTECH AUTOMAÇÃO

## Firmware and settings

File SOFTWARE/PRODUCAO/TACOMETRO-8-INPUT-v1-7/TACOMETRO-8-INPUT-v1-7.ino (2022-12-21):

/*
 ----------------------------------------------------------
|   PROJETO  : TACOMETRO 8 INPUT via rede 485               |
|   AUTOR    : STENIO RODRIGUES                             |
|   DATA     : 02/05/2022                                   |
|   OBJETIVO :                                              |
|               Apontar conversão de sensor tipo encoder    |
|               escala 100p/volta para RPM via rede 485     |
|               aplicação industrial geral.                 |
|   Atualização: Método de rede, sequenciar  respostas      |
|                em cascata dos clientes baseado na         |
|                multiplexação de 3 portas digitais         |
|                                                           |
 ----------------------------------------------------------
   Organização do código.
    // =================================================================================
    // --- Bibliotecas Auxiliares       --- //
    // =================================================================================
    // --- Mapeamento de Hardware       --- //
    // =================================================================================
    // --- Variáveis Globais            --- //
    // =================================================================================
    // --- Instâncias                   --- //
    // =================================================================================
    // --- Protótipo das Funções        --- //
    // =================================================================================
    // --- Interrupções                 --- //
    // =================================================================================
    // --- Configurações Iniciais SETUP --- //
    // =================================================================================
    // --- Loop Infinito                --- //
    // =================================================================================
    // --- Desenvolvimento das Funções  --- //
    // =================================================================================
 */
// =================================================================================
// --- Bibliotecas Auxiliares       --- //
#include <avr/io.h>  // wachdog
#include <avr/wdt.h> // wachdog
  
// =================================================================================
// --- Mapeamento de Hardware       --- //
//Portas analogicas     A0 A1 A2 A3 A4 A5
//Portas Digitais 12 13 14 15 16 17 18 19
const int PinB0 = A3;
const int PinB1 = A4;
const int PinB2 = A5;

const int bit_end_0 = 10;
const int bit_end_1 = 11;
const int bit_end_2 = 12;
const int MASTER = 13;

#define Pbit_0 14 // A0 
#define Pbit_1 15 // A1
#define Pbit_2 16 // A2 

// ---  mapeamento de hardware      --- //
const byte pin_02 = (1 << 2);//(1 << 2); //2;
const byte pin_03 = (1 << 3);
const byte pin_04 = (1 << 4);
const byte pin_05 = (1 << 5);
const byte pin_06 = (1 << 6);
const byte pin_07 = (1 << 7); 
const byte pin_08 = (1 << 0);
const byte pin_09 = (1 << 1);
// =================================================================================
// --- Variáveis Globais            --- //

unsigned long 
              timeold           = 0,        // Variavel conta tempo em milis contador
              timeold_end       = 0;        // Variavel conta tempo em milis disparo 

unsigned int  pulsos_por_volta  = 200;

int 
              teste             = 0,
              end_cliente_num   = 0,
              conversor         = 1,
              bit_0             = 0,
              bit_1             = 0,
              bit_2             = 0,
              pulsos_2          = 0,
              pulsos_3          = 0,
              pulsos_4          = 0,
              pulsos_5          = 0,
              pulsos_6          = 0,
              pulsos_7          = 0,
              pulsos_8          = 0,
              pulsos_9          = 0,
              marcador_cliente  = 0,
              freq_sensor       = 0;

String
              str         = "",                                   // string de buffer de caracteres rede 485
              str_sensor  = "",
              str_BASE    = "",
              end_CONF    = "";

volatile byte 
              state_D2          = LOW, 
              state_D3          = LOW,
              state_D4          = LOW,
              state_D5          = LOW,
              state_D6          = LOW,
              state_D7          = LOW,
              state_D8          = LOW,
              state_D9          = LOW;

// =================================================================================
// --- Protótipo das Funções        --- //
// Função que alterar porta digitais para definir qual cliente responde solicitação
void Chama_cliente          (int end_bit_client                                         );
// Retorna qual endereço de cliente está falando
int  Qual_cliente           (                                                           );
// Retorna qual endereço de cliente está falando para teste
void Debug_qual_cliente     (                                                           );
// Gerador de endereços de clientes na rede para teste
void Debug_gerador_endereco (                                                           );
// Define endereço do micro baseado nos pinos de entrada uma tabela binaria orienta a config
void Gerenciador_endereco   (                                                           );
// Contador de pulsos das entradas dos sensores.
int  Contador               (                                                           );
// Monta o vetor com pulsos convertidas em RPM simples, sem média movel dado bruto
void Vetor_RPM              (float ref_temp,int n_pulso,int n_pulso_volta,int end_sensor);
// abre e fecha a rede 485 função herdada termometria
void Proto_485_V2           (String end_cliente, String msg_cliente                     );
// temperatura convertida enviada via rede 
void Imprimir_serial_temp   (                                                           );
// Simula pulsos para teste sem usar o motor
void Simu_Sensor            (int temp                                                   );

// =================================================================================
// --- Configurações Iniciais SETUP --- //
void setup() {
   wdt_disable  (                     ); // desativa o dog
   wdt_enable   (WDTO_2S              ); //    /*#define WDTO_15MS,30MS,60MS,120MS,250MS,500MS,1S,2S,4S,8S*/
   // pino responsável por habilitar comunicação serial 485
   pinMode      (MASTER, OUTPUT       );
   // saida endereço de rede
   pinMode      (bit_end_0, OUTPUT    );
   pinMode      (bit_end_1, OUTPUT    );
   pinMode      (bit_end_2, OUTPUT    );
   // entradas endereço da rede
   pinMode      (PinB0, INPUT_PULLUP  );
   pinMode      (PinB1, INPUT_PULLUP  );
   pinMode      (PinB2, INPUT_PULLUP  );
   // configuração entrada sensores

   DDRD &= ~pin_02; // pin_02 o bit 2 do registrador ENTRADA DIGITAL PIN  REGISTRADORES  
   DDRD &= ~pin_03;
   DDRD &= ~pin_04;
   DDRD &= ~pin_05;
   DDRD &= ~pin_06;
   DDRD &= ~pin_07;
   DDRB &= ~pin_08; // note que mudou o registrador de ddrD para ddrB consulte pinout do atmega328PU
   DDRB &= ~pin_09; // pin_09 o bit 9 do registrador ENTRADA DIGITAL PIN  REGISTRADORES 

   PORTD |= pin_02; // ATIVANDO PULLUP CORRIGIR BUG LEITURA FALSA
   PORTD |= pin_03;
   PORTD |= pin_04;
   PORTD |= pin_05;
   PORTD |= pin_06;
   PORTD |= pin_07;
   PORTB |= pin_08; // note mudança do portD para portB
   PORTB |= pin_09;
   // entrada endereço interno cliente
   pinMode(Pbit_0, INPUT_PULLUP);
   pinMode(Pbit_1, INPUT_PULLUP);
   pinMode(Pbit_2, INPUT_PULLUP);
   // armazenando endereço configurado para essa unidade
   bit_0 = digitalRead(Pbit_0);
   bit_1 = digitalRead(Pbit_1);
   bit_2 = digitalRead(Pbit_2);

   // partindo saidas digitais nivel baixo
   digitalWrite(bit_end_0, LOW);
   digitalWrite(bit_end_1, LOW);
   digitalWrite(bit_end_2, LOW);
   digitalWrite(MASTER, LOW);
   Serial.begin(9600);
   Serial.println("Arquivo:TACOMETRO-8-INPUT-v1-7...\n");
   //Serial.print("Rotina ativa: ");
   //Serial.print("Simu_Sensor  (temp );\n");

   Gerenciador_endereco();
   wdt_reset(); // reinicia contador de cachorrão!!!!
} // end SETUP
// PROTOCOLO DE REDE INTERNA ATUAL
    /* O cliente 1  envia via sua leitura via rede e depois
        muda o estado das portas para o cliente numero 2 responder espera o timeout
        depois muda estado das portas para o cliente 3... até voltar ele de novo. */
// FUNCIONAMENTO DO PRODUTO
    /* O programa lê o endereço do cliente configurado por meio de dip switchs com 3 pontos
       representadano uma sequencia binaria b0b1b2 onde teremos as combinações:
       cliente 1        001 
       cliente 3        011 
       como exemplo das possíveis combinações
       depois dessa configuração inicial o produto le as portas destinadas a demanda de rede
       nessa etapa ele compara se recebeu comando externo para responder uma solicitação
       via rede 485 ou se segue para a rotina de leitura e processamento dos pulsos dos sensores
       a janela de intervalo de respostas para uma solicitação de rede é de 1 segundo */
void loop() {
  wdt_reset               (     );
   /////// ---  Debug gerador de cliente --- ///////
   // Debug_gerador_endereco ();
 
   teste = Qual_cliente   (     ); // aponta qual cliente está permitido falar na rede
   Contador               (     );// SEMPRE ATIVO
    if (end_cliente_num == teste )
      {
            Imprimir_serial_temp (     ); // envia via RS485
      }
    if(end_cliente_num == 1){
            Imprimir_serial_temp (     );
        }//end if

   // Rotina para o cliente 1 o gerenciador de rede
      // temporização sem usar delay
  if (millis() - timeold_end >= 1000)
      {
        // temporizador sem usar o delay
        int long timeold_2 = (millis() - timeold_end);
        if (end_cliente_num == 1)
            {
              marcador_cliente = 2;
              Chama_cliente(marcador_cliente);
            }// end if
        timeold_end = millis();
      }// end If
     
///////////////////////////////////////////////////////////////////
// DEBUG REDE PARA TESTE
   //Imprimir_serial_temp (     ); // envia via RS485
  // Rotina simulador de rede
  // freq_sensor=20500;
  // Simu_Sensor  (freq_sensor );
///////////////////////////////////////////////////////////////////

} // END LOOP
 
// =================================================================================
// --- Desenvolvimento das Funções  --- //
void Gerenciador_endereco   (                                                           ) {
   // clinte com todos sensores definir endereço
   if (bit_2 == 0 && bit_1 == 0 && bit_0 == 1) end_cliente_num = 1;
   if (bit_2 == 0 && bit_1 == 1 && bit_0 == 0) end_cliente_num = 2;
   if (bit_2 == 0 && bit_1 == 1 && bit_0 == 1) end_cliente_num = 3;
   if (bit_2 == 1 && bit_1 == 0 && bit_0 == 0) end_cliente_num = 4;
   if (bit_2 == 1 && bit_1 == 0 && bit_0 == 1) end_cliente_num = 5;
   if (bit_2 == 1 && bit_1 == 1 && bit_0 == 0) end_cliente_num = 6;
   if (bit_2 == 1 && bit_1 == 1 && bit_0 == 1) end_cliente_num = 7;
   /*
   if (bit_3 == 1 && bit_2 == 0 && bit_1 == 0 && bit_0 == 0 ) end_cliente_num = 8;
   if (bit_3 == 1 && bit_2 == 0 && bit_1 == 0 && bit_0 == 1 ) end_cliente_num = 9;
   if (bit_3 == 1 && bit_2 == 0 && bit_1 == 1 && bit_0 == 0 ) end_cliente_num = 10;
   if (bit_3 == 1 && bit_2 == 0 && bit_1 == 1 && bit_0 == 1 ) end_cliente_num = 11;
   if (bit_3 == 1 && bit_2 == 1 && bit_1 == 0 && bit_0 == 0 ) end_cliente_num = 12;
   if (bit_3 == 1 && bit_2 == 1 && bit_1 == 0 && bit_0 == 1 ) end_cliente_num = 13;
   if (bit_3 == 1 && bit_2 == 1 && bit_1 == 1 && bit_0 == 0 ) end_cliente_num = 14;
   if (bit_3 == 1 && bit_2 == 1 && bit_1 == 1 && bit_0 == 1 ) end_cliente_num = 15;*/
      Serial.print("ENDERECO CONVERSOR: ");
      Serial.println(end_cliente_num);
      switch (end_cliente_num) {
              case 1:
                  end_CONF = "P001*";
                  break;
              case 2:
                  end_CONF = "P002*";
                  break;
              case 3:
                  end_CONF = "P003*";
                  break;
              case 4:
                  end_CONF = "P004*";
                  break;
              case 5:
                  end_CONF = "P005*";
                  break;
              case 6:
                  end_CONF = "P006*";
                  break;
              case 7:
                  end_CONF = "P007*";
                  break;
              case 8:
                  end_CONF = "P008*";
                  break;
              case 9:
                  end_CONF = "P009*";
                  break;
              case 10:
                  end_CONF = "P010*";
                  break;
              case 11:
                  end_CONF = "P011*";
                  break;
              case 12:
                  end_CONF = "P012*";
                  break;
              case 13:
                  end_CONF = "P013*";
                  break;
              case 14:
                  end_CONF = "P014*";
                  break;
              case 15:
                  end_CONF = "P015*";
                  break;
              default:
                  Serial.print("ERRO AO CONFIGURAR ENDERECO CONVERSOR: ");
                  wdt_reset();
                  break;
      } // END SWITCH
} // end Gerenciador_endereco
// =================================================================================
void Debug_gerador_endereco (                                                           ) {
   for (size_t i = 1; i <= 4; i++) {
      delay(1000);
      Chama_cliente(i);
      Serial.println(i);
      delay(2000);
   } // end for
} // End gerador de endereços sequenciais
// =================================================================================
void Debug_qual_cliente     (                                                           ) {
   //teste = Qual_cliente();
   Serial.print("CLIENTE: ");
   Serial.println(teste);
   delay(500);
   /*
      Serial.println("B2  B1  B0:");
      Serial.print(digitalRead(PinB2));
      Serial.print(" :  ");
      Serial.print(digitalRead(PinB1));
      Serial.print(" :  ");
      Serial.print(digitalRead(PinB0));
      Serial.println(" "); */
} // fim debug entrada endereço rede
// =================================================================================
void Chama_cliente          (int end_bit_client                                         ) {
   /* TABELA VERDADE ENDEREÇO CLIENTE
   bit_end_2 bit_end_1 bit_end_0 
       0         0         1       /// cliente 1
       0         1         0       /// cliente 2
       0         1         1       /// cliente 3
       1         0         0       /// cliente 4 */
   switch (end_bit_client) {
            case 1:
                digitalWrite(bit_end_0, LOW);
                digitalWrite(bit_end_1, HIGH);
                digitalWrite(bit_end_2, HIGH);
                break;
            case 2:
                digitalWrite(bit_end_0, HIGH);
                digitalWrite(bit_end_1, LOW);
                digitalWrite(bit_end_2, HIGH);
                break;
            case 3:
                digitalWrite(bit_end_0, LOW);
                digitalWrite(bit_end_1, LOW);
                digitalWrite(bit_end_2, HIGH);
                break;
            case 4:
                digitalWrite(bit_end_0, HIGH);
                digitalWrite(bit_end_1, HIGH);
                digitalWrite(bit_end_2, LOW);
                break;
            default:
                digitalWrite(bit_end_0, HIGH);
                digitalWrite(bit_end_1, HIGH);
                digitalWrite(bit_end_2, HIGH);
                break;
   } // end switch
} // End Chama_cliente_2
// =================================================================================
int Qual_cliente            (                                                           ) {
   /* TABELA VERDADE ENDEREÇO CLIENTE
   bit_end_2 bit_end_1 bit_end_0 
       0         0         1       /// cliente 1
       0         1         0       /// cliente 2
       0         1         1       /// cliente 3
       1         0         0       /// cliente 4 */
   int qual_cliente = 0;
   int leitura_bit_0 = digitalRead(PinB0);
   int leitura_bit_1 = digitalRead(PinB1);
   int leitura_bit_2 = digitalRead(PinB2);
      if (leitura_bit_2 == 0 && leitura_bit_1 == 0 && leitura_bit_0 == 1) qual_cliente = 1;
      if (leitura_bit_2 == 0 && leitura_bit_1 == 1 && leitura_bit_0 == 0) qual_cliente = 2;
      if (leitura_bit_2 == 0 && leitura_bit_1 == 1 && leitura_bit_0 == 1) qual_cliente = 3;
      if (leitura_bit_2 == 1 && leitura_bit_1 == 0 && leitura_bit_0 == 0) qual_cliente = 4;
      if (leitura_bit_2 == 1 && leitura_bit_1 == 1 && leitura_bit_0 == 1) qual_cliente = 9;
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

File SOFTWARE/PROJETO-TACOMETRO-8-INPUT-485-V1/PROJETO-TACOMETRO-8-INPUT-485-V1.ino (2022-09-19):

/*
 ----------------------------------------------------------
|   PROJETO  : TACOMETRO 8 INPUT via rede 485               |
|   AUTOR    : STENIO RODRIGUES                             |
|   DATA     : 02/05/2022                                   |
|   OBJETIVO :                                              |
|             Apontar conversão de sensor tipo encoder      |
|               escala 100p/volta para RPM via rede 485     |
|              aplicação industrial geral.                  |
|   Atualização: Método de rede, sequenciar  respostas      |
|                em cascata dos clientes baseado na         |
|               quantidade de clientes e Mudança de I/O     |
|                                                           |
 ----------------------------------------------------------
   Organização do código.
    // =================================================================================
    // --- Bibliotecas Auxiliares       --- //
    // =================================================================================
    // --- Mapeamento de Hardware       --- //
    // =================================================================================
    // --- Variáveis Globais            --- //
    // =================================================================================
    // --- Instâncias                   --- //
    // =================================================================================
    // --- Protótipo das Funções        --- //
    // =================================================================================
    // --- Interrupções                 --- //
    // =================================================================================
    // --- Configurações Iniciais SETUP --- //
    // =================================================================================
    // --- Loop Infinito                --- //
    // =================================================================================
    // --- Desenvolvimento das Funções  --- //
    // =================================================================================
 */

// --- Bibliotecas Auxiliares       --- //
#include <avr/io.h>  // wachdog
#include <avr/wdt.h> // wachdog

// =================================================================================
// ---  mapeamento de hardware      --- //
const byte pin_02 = (1 << 2); //2;
const byte pin_03 = (1 << 3);
const byte pin_04 = (1 << 4);
const byte pin_05 = (1 << 5);
const byte pin_06 = (1 << 6);
const byte pin_07 = (1 << 7);
const byte pin_08 = (1 << 0);
const byte pin_09 = (1 << 1);
//Portas analogicas     A0 A1 A2 A3 A4 A5
//Portas Digitais 12 13 14 15 16 17 18 19
int MASTER = 13;
#define Pbit_0 14    // A0 
#define Pbit_1 15    // A1
#define Pbit_2 16    // A2 

#define Pbit_3 17    // A3 
#define Pbit_A 18    // A4 
#define Pbit_B 19    // A5 
// =================================================================================
// --- Variáveis Globais            --- //
int   pulsos_2          = 0,
      ciclos1           = 0,
      pulsos_3          = 0,
      pulsos_4          = 0,
      pulsos_5          = 0,
      conta_caracter    = 0,
      pulsos_6          = 0,
      pulsos_7          = 0,
      pulsos_8          = 0,
      pulsos_9          = 0,
      temp              = 0,
      ident_sensor_G    = 0;

//volatile byte pulsos;
unsigned long timeold   = 0;
//Altere o numero abaixo de acordo com o seu disco encoder
unsigned int   pulsos_por_volta  = 200;
volatile byte  state_D2          = LOW, 
               state_D3          = LOW,
               state_D4          = LOW,
               state_D5          = LOW,
               state_D6          = LOW,
               state_D7          = LOW,
               state_D8          = LOW,
               state_D9          = LOW;

#define num 10 //número de iterações da média móvel
float           results_G             = 0.00,               // armazena leitura conversor A/D
                results1_G            = 0.00,
                results2_G            = 0.00,
                results3_G            = 0.00,
                results4_G            = 0.00,
                results5_G            = 0.00,
                results6_G            = 0.00,
                results7_G            = 0.00,
                results8_G            = 0.00,
                values_G [num],                              // vetor de iteração de média móvel
                values1_G[num],
                values2_G[num],
                values3_G[num],
                values4_G[num],
                values5_G[num],
                values6_G[num],
                values7_G[num],
                values8_G[num];

String   str         = "",                                   // string de buffer de caracteres rede 485
         str_sensor  = "",
         str_BASE    = "",
         end_CONF    = "";

const int tam_msg = 62; 
char    charRecebida[tam_msg],                              // vetor de buffer rede 485
        str1[tam_msg],
        char_pulsos[9];
int   end_cliente_num   =0, 
      conversor         =1,
      bit_0,
      bit_1,
      bit_2,
      bit_3,
      bit_A,
      bit_B;

// =================================================================================
// --- Instâncias                   --- //

// --- Protótipo das Funções        --- //

// Pra que server
// tantos códigos?
// Se a vida
// não é programada
// e as melhores coisas
// não tem lógica
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

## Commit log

2022-05-12 Modelagem 3D
    [CAIXA-INFERIOR-REDE-V1.STL, CASE IO V1.STL, CASE TAMPA V2.STL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]
2022-05-12 Modelagem PCB
2022-05-12 Referencias e pesquisas
    [calculo rotação.xlsx]
2022-05-12 Lista de materiais desatualizada
    [LISTA DE MATERIAIS DESATUALIZADO.xlsx]
2022-05-12 Teste de função identificar endereço cliente e responder adequadamente
    Funções que deverão identificar qual cliente está falando dependendo as entradas opto isoladas
2022-05-13 Teste protocolo de rede
2022-05-13 O debug serial rodou liso com dois cliente sem rede
    Falta alimentar o segundo circuito de realimentação dos endereços de rede e testar. Circuito provisório montado na protoboard.
2022-05-18 Atualização da lista de materiais
    [LISTA DE MATERIAIS em 18-05-22.xlsx]
2022-06-06 TEMP SIMULACAO PCB
2022-06-17 Lista de materiais
    [LISTA DE MATERIAIS DESATUALIZADO.xlsx, LISTA DE MATERIAIS aplicada 17-06-22.xlsx, LISTA DE MATERIAIS em 18-05-22.xlsx]
2022-07-12 Ajuste PCB erros furos
2022-07-29 Manual de montagem e instalação
    [CASE TAMPA V9.STL, COLAR-P1-V2.STL, PINO-GUIA-V2.STL]
2022-09-19 Correção PCB
2022-09-19 Modelagem 3D cases
    [CAIXA-DIN-FONTE-V3.STL, CAIXA-DIN-FONTE-V4.STL, CAIXA-DIN-REDE-V3.STL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]
